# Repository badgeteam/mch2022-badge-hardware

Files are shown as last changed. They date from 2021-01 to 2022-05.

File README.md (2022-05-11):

# MCH2022 badge hardware

The hardware design files for the MCH2022 event badge.

## Documentation

Detailed information can be found on our website at https://badge.team/docs/badges/mch2022/.

Need the schematic? [It's in this repository as a PDF file](schematic.pdf).

## Firmware

There are multiple processors on this board, the firmware flashed on to the board in the factory can be found in the following repositories:

 - https://github.com/badgeteam/mch2022-firmware-esp32
 - https://github.com/badgeteam/mch2022-firmware-rp2040

## License

This hardware design may be used under the terms of the [CERN-OHL-P](LICENSE) license.

## Authors

The artwork featured in this hardware design has been designed by Nikolett S. from [tilde.industries](https://tilde.industries).

The electronics have been designed by Renze Nicolai from [Nicolai Electronics](https://nicolaielectronics.nl).

A special thanks to all who contributed by helping with the routing and by debugging the hardware design:

 - Anne Jan Brouwer
 - Kliment Yanev
 - Kuristian
 - Martin Ling
 - Paul Honig
 - Sylvain Munaut
 - Tom Clement
 - Fuchsia (f0x)
 - Sander de Haan

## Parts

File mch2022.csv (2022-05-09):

Source: | /home/renze/Documents/Badge.team/mch2022-badge-hardware/mch2022.kicad_sch
Date: | Mon 09 May 2022 05:42:22 PM CEST
Tool: | Eeschema (6.0.5)
Generator: | /usr/share/kicad/plugins/bom_csv_grouped_by_value.py
Component Count: | 235
Individual Components:
Item | Qty | Reference(s) | Value | LibPart | Footprint | Datasheet | AVAILABILITY | Buy early | Category | DESCRIPTION | DK_Datasheet_Link | DK_Detail_Page | Description | Digi-Key_PN | Family | Field4 | LCSC | MANUFACTURER | MAXIMUM_PACKAGE_HEIGHT | MF | MP | MPN | Manufacturer | Minimal voltage rating | Mouser | PACKAGE | PARTREV | PRICE | Price | STANDARD | Sponsored | Status | Voltage rating
 |  | C1 | 1u | mch2021-rescue:C-Device | Capacitor_SMD:C_0402_1005Metric | https://datasheet.lcsc.com/lcsc/1810191216_Samsung-Electro-Mechanics-CL05A105KQ5NNNC_C107372.pdf |  | Y | Capacitors |  |  |  | Generic part |  |  |  | C107372 |  |  |  |  | CL05A105KQ5NNNC | Samsung Electro-Mechanics | 6 |  |  |  |  |  |  | N |  | 6.3
 |  | C3 | 100n | mch2021-rescue:C-Device | Capacitor_SMD:C_0402_1005Metric | https://datasheet.lcsc.com/lcsc/1810191222_Samsung-Electro-Mechanics-CL05B104KB54PNC_C307331.pdf |  | Y | Capacitors |  |  |  | Generic part |  |  |  | C307331 |  |  |  |  | CL05B104KB54PNC | Samsung Electro-Mechanics | 10 |  |  |  |  |  |  | N |  | 50
 |  | C4 | 100n | Device:C_Small | Capacitor_SMD:C_0402_1005Metric | https://datasheet.lcsc.com/lcsc/1810191222_Samsung-Electro-Mechanics-CL05B104KB54PNC_C307331.pdf |  | Y | Capacitors |  |  |  | Generic part |  |  |  | C307331 |  |  |  |  | CL05B104KB54PNC | Samsung Electro-Mechanics | 10 |  |  |  |  |  |  | N |  | 50
 |  | C5 | 47u | Device:C_Small | Capacitor_SMD:C_0805_2012Metric | https://datasheet.lcsc.com/lcsc/1811091612_Samsung-Electro-Mechanics-CL21A476MQYNNNE_C16780.pdf |  | Y | Capacitors |  |  |  | Generic part |  |  |  | C16780 |  |  |  |  | CL21A476MQYNNNE | Samsung Electro-Mechanics | 6 |  |  |  |  |  |  | N |  | 6.3
 |  | C6 | 47u | Device:C_Small | Capacitor_SMD:C_0805_2012Metric | https://datasheet.lcsc.com/lcsc/1811091612_Samsung-Electro-Mechanics-CL21A476MQYNNNE_C16780.pdf |  | Y | Capacitors |  |  |  | Generic part |  |  |  | C16780 |  |  |  |  | CL21A476MQYNNNE | Samsung Electro-Mechanics | 6 |  |  |  |  |  |  | N |  | 6.3
 |  | C7 | 100n | mch2021-rescue:C-Device | Capacitor_SMD:C_0402_1005Metric | https://datasheet.lcsc.com/lcsc/1810191222_Samsung-Electro-Mechanics-CL05B104KB54PNC_C307331.pdf |  | Y | Capacitors |  |  |  | Generic part |  |  |  | C307331 |  |  |  |  | CL05B104KB54PNC | Samsung Electro-Mechanics | 10 | - |  |  |  |  |  | N |  | 50
 |  | C8 | 1u | mch2021-rescue:C-Device | Capacitor_SMD:C_0402_1005Metric | https://datasheet.lcsc.com/lcsc/1810191216_Samsung-Electro-Mechanics-CL05A105KQ5NNNC_C107372.pdf |  | Y | Capacitors |  |  |  | Generic part |  |  |  | C107372 |  |  |  |  | CL05A105KQ5NNNC | Samsung Electro-Mechanics | 6 | - |  |  |  |  |  | N |  | 6.3
 |  | C9 | 22p | mch2021-rescue:C-Device | Capacitor_SMD:C_0402_1005Metric | https://datasheet.lcsc.com/lcsc/1912111437_CCTC-TCC0402C0G220J500AT_C466226.pdf |  | Y | Capacitors |  |  |  | Generic part |  |  |  | C466226 | YAGEO |  |  |  | TCC0402C0G220J500AT | CCTC | 10 |  |  |  |  |  |  | N |  | 50
 |  | C10 | 22p | mch2021-rescue:C-Device | Capacitor_SMD:C_0402_1005Metric | https://datasheet.lcsc.com/lcsc/1912111437_CCTC-TCC0402C0G220J500AT_C466226.pdf |  | Y | Capacitors |  |  |  | Generic part |  |  |  | C466226 | YAGEO |  |  |  | TCC0402C0G220J500AT | CCTC | 10 |  |  |  |  |  |  | N |  | 50
 |  | C11 | 100n | mch2021-rescue:C-Device | Capacitor_SMD:C_0402_1005Metric | https://datasheet.lcsc.com/lcsc/1810191222_Samsung-Electro-Mechanics-CL05B104KB54PNC_C307331.pdf |  | Y | Capacitors |  |  |  | Generic part |  |  |  | C307331 |  |  |  |  | CL05B104KB54PNC | Samsung Electro-Mechanics | 10 | - |  |  |  |  |  | N |  | 50
 |  | C12 | 100n | mch2021-rescue:C_Small-Device | Capacitor_SMD:C_0402_1005Metric | https://datasheet.lcsc.com/lcsc/1810191222_Samsung-Electro-Mechanics-CL05B104KB54PNC_C307331.pdf |  | Y | Capacitors |  |  |  | Generic part |  |  |  | C307331 |  |  |  |  | CL05B104KB54PNC | Samsung Electro-Mechanics | 10 | - |  |  |  |  |  | N |  | 50
 |  | C13 | 100n | mch2021-rescue:C-Device | Capacitor_SMD:C_0402_1005Metric | https://datasheet.lcsc.com/lcsc/1810191222_Samsung-Electro-Mechanics-CL05B104KB54PNC_C307331.pdf |  | Y | Capacitors |  |  |  | Generic part |  |  |  | C307331 |  |  |  |  | CL05B104KB54PNC | Samsung Electro-Mechanics | 10 | - |  |  |  |  |  | N |  | 50
 |  | C14 | 100n | Device:C_Small | Capacitor_SMD:C_0402_1005Metric | https://datasheet.lcsc.com/lcsc/1810191222_Samsung-Electro-Mechanics-CL05B104KB54PNC_C307331.pdf |  | Y | Capacitors |  |  |  | Generic part |  |  |  | C307331 |  |  |  |  | CL05B104KB54PNC | Samsung Electro-Mechanics | 10 |  |  |  |  |  |  | N |  | 50
 |  | C15 | 100n | mch2021-rescue:C_Small-Device | Capacitor_SMD:C_0402_1005Metric | https://datasheet.lcsc.com/lcsc/1810191222_Samsung-Electro-Mechanics-CL05B104KB54PNC_C307331.pdf |  | Y | Capacitors |  |  |  | Generic part |  |  |  | C307331 |  |  |  |  | CL05B104KB54PNC | Samsung Electro-Mechanics | 10 | - |  |  |  |  |  | N |  | 50
 |  | C16 | 100n | mch2021-rescue:C_Small-Device | Capacitor_SMD:C_0402_1005Metric | https://datasheet.lcsc.com/lcsc/1810191222_Samsung-Electro-Mechanics-CL05B104KB54PNC_C307331.pdf |  | Y | Capacitors |  |  |  | Generic part |  |  |  | C307331 |  |  |  |  | CL05B104KB54PNC | Samsung Electro-Mechanics | 10 | - |  |  |  |  |  | N |  | 50
 |  | C17 | 10u | mch2021-rescue:C_Small-Device | Capacitor_SMD:C_0402_1005Metric | https://datasheet.lcsc.com/lcsc/1810191215_Samsung-Electro-Mechanics-CL05A106MQ5NUNC_C15525.pdf |  | Y | Capacitors |  |  |  | Generic part |  |  |  | C15525 |  |  |  |  | CL05A106MQ5NUNC | Samsung Electro-Mechanics | 6 |  |  |  |  |  |  | N |  | 6.3
 |  | C18 | 100n | mch2021-rescue:C_Small-Device | Capacitor_SMD:C_0402_1005Metric | https://datasheet.lcsc.com/lcsc/1810191222_Samsung-Electro-Mechanics-CL05B104KB54PNC_C307331.pdf |  | Y | Capacitors |  |  |  | Generic part |  |  |  | C307331 |  |  |  |  | CL05B104KB54PNC | Samsung Electro-Mechanics | 10 | - |  |  |  |  |  | N |  | 50
 |  | C19 | 100n | mch2021-rescue:C_Small-Device | Capacitor_SMD:C_0402_1005Metric | https://datasheet.lcsc.com/lcsc/1810191222_Samsung-Electro-Mechanics-CL05B104KB54PNC_C307331.pdf |  | Y | Capacitors |  |  |  | Generic part |  |  |  | C307331 |  |  |  |  | CL05B104KB54PNC | Samsung Electro-Mechanics | 10 | - |  |  |  |  |  | N |  | 50
 |  | C20 | 100n | mch2021-rescue:C_Small-Device | Capacitor_SMD:C_0402_1005Metric | https://datasheet.lcsc.com/lcsc/1810191222_Samsung-Electro-Mechanics-CL05B104KB54PNC_C307331.pdf |  | Y | Capacitors |  |  |  | Generic part |  |  |  | C307331 |  |  |  |  | CL05B104KB54PNC | Samsung Electro-Mechanics | 10 | - |  |  |  |  |  | N |  | 50
 |  | C21 | 100n | mch2021-rescue:C_Small-Device | Capacitor_SMD:C_0402_1005Metric | https://datasheet.lcsc.com/lcsc/1810191222_Samsung-Electro-Mechanics-CL05B104KB54PNC_C307331.pdf |  | Y | Capacitors |  |  |  | Generic part |  |  |  | C307331 |  |  |  |  | CL05B104KB54PNC | Samsung Electro-Mechanics | 10 | - |  |  |  |  |  | N |  | 50
 |  | C22 | 100n | mch2021-rescue:C_Small-Device | Capacitor_SMD:C_0402_1005Metric | https://datasheet.lcsc.com/lcsc/1810191222_Samsung-Electro-Mechanics-CL05B104KB54PNC_C307331.pdf |  | Y | Capacitors |  |  |  | Generic part |  |  |  | C307331 |  |  |  |  | CL05B104KB54PNC | Samsung Electro-Mechanics | 10 | - |  |  |  |  |  | N |  | 50
 |  | C23 | 100n | mch2021-rescue:C-Device | Capacitor_SMD:C_0402_1005Metric | https://datasheet.lcsc.com/lcsc/1810191222_Samsung-Electro-Mechanics-CL05B104KB54PNC_C307331.pdf |  | Y | Capacitors |  |  |  | Generic part |  |  |  | C307331 |  |  |  |  | CL05B104KB54PNC | Samsung Electro-Mechanics | 10 | - |  |  |  |  |  | N |  | 50
 |  | C24 | 100n | mch2021-rescue:C-Device | Capacitor_SMD:C_0402_1005Metric | https://datasheet.lcsc.com/lcsc/1810191222_Samsung-Electro-Mechanics-CL05B104KB54PNC_C307331.pdf |  | Y | Capacitors |  |  |  | Generic part |  |  |  | C307331 |  |  |  |  | CL05B104KB54PNC | Samsung Electro-Mechanics | 10 | - |  |  |  |  |  | N |  | 50
 |  | C25 | 10u | mch2021-rescue:C-Device | Capacitor_SMD:C_0402_1005Metric | https://datasheet.lcsc.com/lcsc/1810191215_Samsung-Electro-Mechanics-CL05A106MQ5NUNC_C15525.pdf |  | Y | Capacitors |  |  |  | Generic part |  |  |  | C15525 |  |  |  |  | CL05A106MQ5NUNC | Samsung Electro-Mechanics | 6 |  |  |  |  |  |  | N |  | 6.3
 |  | C26 | 100n | mch2021-rescue:C-Device | Capacitor_SMD:C_0402_1005Metric | https://datasheet.lcsc.com/lcsc/1810191222_Samsung-Electro-Mechanics-CL05B104KB54PNC_C307331.pdf |  | Y | Capacitors |  |  |  | Generic part |  |  |  | C307331 |  |  |  |  | CL05B104KB54PNC | Samsung Electro-Mechanics | 10 | - |  |  |  |  |  | N |  | 50
 |  | C27 | 100n | mch2021-rescue:C-Device | Capacitor_SMD:C_0402_1005Metric | https://datasheet.lcsc.com/lcsc/1810191222_Samsung-Electro-Mechanics-CL05B104KB54PNC_C307331.pdf |  | Y | Capacitors |  |  |  | Generic part |  |  |  | C307331 |  |  |  |  | CL05B104KB54PNC | Samsung Electro-Mechanics | 10 | - |  |  |  |  |  | N |  | 50
 |  | C28 | 22p | mch2021-rescue:C-Device | Capacitor_SMD:C_0402_1005Metric | https://datasheet.lcsc.com/lcsc/1912111437_CCTC-TCC0402C0G220J500AT_C466226.pdf |  | Y | Capacitors |  |  |  | Generic part |  |  |  | C466226 | YAGEO |  |  |  | TCC0402C0G220J500AT | CCTC | 10 |  |  |  |  |  |  | N |  | 50
 |  | C29 | 22p | mch2021-rescue:C-Device | Capacitor_SMD:C_0402_1005Metric | https://datasheet.lcsc.com/lcsc/1912111437_CCTC-TCC0402C0G220J500AT_C466226.pdf |  | Y | Capacitors |  |  |  | Generic part |  |  |  | C466226 | YAGEO |  |  |  | TCC0402C0G220J500AT | CCTC | 10 |  |  |  |  |  |  | N |  | 50
 |  | C30 | 100n | mch2021-rescue:C-Device | Capacitor_SMD:C_0402_1005Metric | https://datasheet.lcsc.com/lcsc/1810191222_Samsung-Electro-Mechanics-CL05B104KB54PNC_C307331.pdf |  | Y | Capacitors |  |  |  | Generic part |  |  |  | C307331 |  |  |  |  | CL05B104KB54PNC | Samsung Electro-Mechanics | 10 | - |  |  |  |  |  | N |  | 50
 |  | C31 | 1u | mch2021-rescue:C-Device | Capacitor_SMD:C_0402_1005Metric | https://datasheet.lcsc.com/lcsc/1810191216_Samsung-Electro-Mechanics-CL05A105KQ5NNNC_C107372.pdf |  | Y | Capacitors |  |  |  | Generic part |  |  |  | C107372 |  |  |  |  | CL05A105KQ5NNNC | Samsung Electro-Mechanics | 6 |  |  |  |  |  |  | N |  | 6.3
 |  | C32 | 1u | mch2021-rescue:C-Device | Capacitor_SMD:C_0402_1005Metric | https://datasheet.lcsc.com/lcsc/1810191216_Samsung-Electro-Mechanics-CL05A105KQ5NNNC_C107372.pdf |  | Y | Capacitors |  |  |  | Generic part |  |  |  | C107372 |  |  |  |  | CL05A105KQ5NNNC | Samsung Electro-Mechanics | 6 |  |  |  |  |  |  | N |  | 6.3
 |  | C33 | 100n | Device:C_Small | Capacitor_SMD:C_0402_1005Metric | https://datasheet.lcsc.com/lcsc/1810191222_Samsung-Electro-Mechanics-CL05B104KB54PNC_C307331.pdf |  | Y | Capacitors |  |  |  | Generic part |  |  |  | C307331 |  |  |  |  | CL05B104KB54PNC | Samsung Electro-Mechanics | 10 |  |  |  |  |  |  | N |  | 50
 |  | C34 | 10u | mch2021-rescue:C-Device | Capacitor_SMD:C_0402_1005Metric | https://datasheet.lcsc.com/lcsc/1810191215_Samsung-Electro-Mechanics-CL05A106MQ5NUNC_C15525.pdf |  | Y | Capacitors |  |  |  | Generic part |  |  |  | C15525 |  |  |  |  | CL05A106MQ5NUNC | Samsung Electro-Mechanics | 6 |  |  |  |  |  |  | N |  | 6.3
 |  | C35 | 100n | mch2021-rescue:C-Device | Capacitor_SMD:C_0402_1005Metric | https://datasheet.lcsc.com/lcsc/1810191222_Samsung-Electro-Mechanics-CL05B104KB54PNC_C307331.pdf |  | Y | Capacitors |  |  |  | Generic part |  |  |  | C307331 |  |  |  |  | CL05B104KB54PNC | Samsung Electro-Mechanics | 10 |  |  |  |  |  |  | N |  | 50
 |  | C36 | 100n | mch2021-rescue:C-Device | Capacitor_SMD:C_0402_1005Metric | https://datasheet.lcsc.com/lcsc/1810191222_Samsung-Electro-Mechanics-CL05B104KB54PNC_C307331.pdf |  | Y | Capacitors |  |  |  | Generic part |  |  |  | C307331 |  |  |  |  | CL05B104KB54PNC | Samsung Electro-Mechanics | 10 |  |  |  |  |  |  | N |  | 50
 |  | C37 | 100n | mch2021-rescue:C-Device | Capacitor_SMD:C_0402_1005Metric | https://datasheet.lcsc.com/lcsc/1810191222_Samsung-Electro-Mechanics-CL05B104KB54PNC_C307331.pdf |  | Y | Capacitors |  |  |  | Generic part |  |  |  | C307331 |  |  |  |  | CL05B104KB54PNC | Samsung Electro-Mechanics | 10 | - |  |  |  |  |  | N |  | 50
 |  | C38 | 22u | mch2021-rescue:C-Device | Capacitor_SMD:C_0805_2012Metric | https://datasheet.lcsc.com/lcsc/2006102223_Samsung-Electro-Mechanics-CL21A226MAYNNNE_C602037.pdf |  | Y | Capacitors |  |  |  | Generic part |  |  |  | C602037 |  |  |  |  | CL21A226MAYNNNE | Samsung Electro-Mechanics | 10 |  |  |  |  |  |  | N |  | 25
 |  | C39 | 22u | mch2021-rescue:C-Device | Capacitor_SMD:C_0805_2012Metric | https://datasheet.lcsc.com/lcsc/2006102223_Samsung-Electro-Mechanics-CL21A226MAYNNNE_C602037.pdf |  | Y | Capacitors |  |  |  | Generic part |  |  |  | C602037 |  |  |  |  | CL21A226MAYNNNE | Samsung Electro-Mechanics | 10 |  |  |  |  |  |  | N |  | 25
 |  | C40 | 22p | mch2021-rescue:C-Device | Capacitor_SMD:C_0402_1005Metric | https://datasheet.lcsc.com/lcsc/1912111437_CCTC-TCC0402C0G220J500AT_C466226.pdf |  | Y | Capacitors |  |  |  | Generic part |  |  |  | C466226 | YAGEO |  |  |  | TCC0402C0G220J500AT | CCTC | 10 |  |  |  |  |  |  | N |  | 50
 |  | C41 | 22p | mch2021-rescue:C-Device | Capacitor_SMD:C_0402_1005Metric | https://datasheet.lcsc.com/lcsc/1912111437_CCTC-TCC0402C0G220J500AT_C466226.pdf |  | Y | Capacitors |  |  |  | Generic part |  |  |  | C466226 | YAGEO |  |  |  | TCC0402C0G220J500AT | CCTC | 10 |  |  |  |  |  |  | N |  | 50
 |  | C42 | 10u | mch2021-rescue:C-Device | Capacitor_SMD:C_0402_1005Metric | https://datasheet.lcsc.com/lcsc/1810191215_Samsung-Electro-Mechanics-CL05A106MQ5NUNC_C15525.pdf |  | Y | Capacitors |  |  |  | Generic part |  |  |  | C15525 |  |  |  |  | CL05A106MQ5NUNC | Samsung Electro-Mechanics | 6 |  |  |  |  |  |  | N |  | 6.3
 |  | C43 | 22u | mch2021-rescue:C-Device | Capacitor_SMD:C_0805_2012Metric | https://datasheet.lcsc.com/lcsc/2006102223_Samsung-Electro-Mechanics-CL21A226MAYNNNE_C602037.pdf |  | Y | Capacitors |  |  |  | Generic part |  |  |  | C602037 |  |  |  |  | CL21A226MAYNNNE | Samsung Electro-Mechanics | 10 |  |  |  |  |  |  | N |  | 25
 |  | C44 | 22u | mch2021-rescue:C-Device | Capacitor_SMD:C_0805_2012Metric | https://datasheet.lcsc.com/lcsc/2006102223_Samsung-Electro-Mechanics-CL21A226MAYNNNE_C602037.pdf |  | Y | Capacitors |  |  |  | Generic part |  |  |  | C602037 |  |  |  |  | CL21A226MAYNNNE | Samsung Electro-Mechanics | 10 |  |  |  |  |  |  | N |  | 25
 |  | C45 | 22u | mch2021-rescue:C-Device | Capacitor_SMD:C_0805_2012Metric | https://datasheet.lcsc.com/lcsc/2006102223_Samsung-Electro-Mechanics-CL21A226MAYNNNE_C602037.pdf |  | Y | Capacitors |  |  |  | Generic part |  |  |  | C602037 |  |  |  |  | CL21A226MAYNNNE | Samsung Electro-Mechanics | 10 |  |  |  |  |  |  | N |  | 25
 |  | C46 | 22u | mch2021-rescue:C-Device | Capacitor_SMD:C_0805_2012Metric | https://datasheet.lcsc.com/lcsc/2006102223_Samsung-Electro-Mechanics-CL21A226MAYNNNE_C602037.pdf |  | Y | Capacitors |  |  |  | Generic part |  |  |  | C602037 |  |  |  |  | CL21A226MAYNNNE | Samsung Electro-Mechanics | 10 |  |  |  |  |  |  | N |  | 25
 |  | C47 | 39n | Device:C_Small | Capacitor_SMD:C_0402_1005Metric | https://datasheet.lcsc.com/lcsc/2010152035_CCTC-TCC0402X7R393K500AT_C880624.pdf |  | Y | Capacitors |  |  |  | Generic part |  |  |  | C880624 |  |  |  |  | TCC0402X7R393K500AT | CCTC | 10 |  |  |  |  |  |  | N |  | 50
 |  | C48 | 100n | mch2021-rescue:C-Device | Capacitor_SMD:C_0402_1005Metric | https://datasheet.lcsc.com/lcsc/1810191222_Samsung-Electro-Mechanics-CL05B104KB54PNC_C307331.pdf |  | Y | Capacitors |  |  |  | Generic part |  |  |  | C307331 |  |  |  |  | CL05B104KB54PNC | Samsung Electro-Mechanics | 10 | - |  |  |  |  |  | N |  | 50
 |  | C49 | 22u | mch2021-rescue:C-Device | Capacitor_SMD:C_0805_2012Metric | https://datasheet.lcsc.com/lcsc/2006102223_Samsung-Electro-Mechanics-CL21A226MAYNNNE_C602037.pdf |  | Y | Capacitors |  |  |  | Generic part |  |  |  | C602037 |  |  |  |  | CL21A226MAYNNNE | Samsung Electro-Mechanics | 10 |  |  |  |  |  |  | N |  | 25
 |  | C50 | 100n | mch2021-rescue:C-Device | Capacitor_SMD:C_0402_1005Metric | https://datasheet.lcsc.com/lcsc/1810191222_Samsung-Electro-Mechanics-CL05B104KB54PNC_C307331.pdf |  | Y | Capacitors |  |  |  | Generic part |  |  |  | C307331 |  |  |  |  | CL05B104KB54PNC | Samsung Electro-Mechanics | 10 | - |  |  |  |  |  | N |  | 50
 |  | C51 | 39n | Device:C_Small | Capacitor_SMD:C_0402_1005Metric | https://datasheet.lcsc.com/lcsc/2010152035_CCTC-TCC0402X7R393K500AT_C880624.pdf |  | Y | Capacitors |  |  |  | Generic part |  |  |  | C880624 |  |  |  |  | TCC0402X7R393K500AT | CCTC | 10 |  |  |  |  |  |  | N |  | 50
 |  | C52 | 47u | Device:C_Small | Capacitor_SMD:C_0805_2012Metric | https://datasheet.lcsc.com/lcsc/1811091612_Samsung-Electro-Mechanics-CL21A476MQYNNNE_C16780.pdf |  | Y | Capacitors |  |  |  | Generic part |  |  |  | C16780 |  |  |  |  | CL21A476MQYNNNE | Samsung Electro-Mechanics | 6 |  |  |  |  |  |  | N |  | 6.3
 |  | C53 | 47u | Device:C_Small | Capacitor_SMD:C_0805_2012Metric | https://datasheet.lcsc.com/lcsc/1811091612_Samsung-Electro-Mechanics-CL21A476MQYNNNE_C16780.pdf |  | Y | Capacitors |  |  |  | Generic part |  |  |  | C16780 |  |  |  |  | CL21A476MQYNNNE | Samsung Electro-Mechanics | 6 |  |  |  |  |  |  | N |  | 6.3
 |  | C54 | 47u | Device:C_Small | Capacitor_SMD:C_0805_2012Metric | https://datasheet.lcsc.com/lcsc/1811091612_Samsung-Electro-Mechanics-CL21A476MQYNNNE_C16780.pdf |  | Y | Capacitors |  |  |  | Generic part |  |  |  | C16780 |  |  |  |  | CL21A476MQYNNNE | Samsung Electro-Mechanics | 6 |  |  |  |  |  |  | N |  | 6.3
 |  | C55 | 47u | Device:C_Small | Capacitor_SMD:C_0805_2012Metric | https://datasheet.lcsc.com/lcsc/1811091612_Samsung-Electro-Mechanics-CL21A476MQYNNNE_C16780.pdf |  | Y | Capacitors |  |  |  | Generic part |  |  |  | C16780 |  |  |  |  | CL21A476MQYNNNE | Samsung Electro-Mechanics | 6 |  |  |  |  |  |  | N |  | 6.3
 |  | C56 | 100n | Device:C_Small | Capacitor_SMD:C_0402_1005Metric | https://datasheet.lcsc.com/lcsc/1810191222_Samsung-Electro-Mechanics-CL05B104KB54PNC_C307331.pdf |  | Y | Capacitors |  |  |  | Generic part |  |  |  | C307331 |  |  |  |  | CL05B104KB54PNC | Samsung Electro-Mechanics | 10 |  |  |  |  |  |  | N |  | 50
 |  | C57 | 47u | Device:C_Small | Capacitor_SMD:C_0805_2012Metric | https://datasheet.lcsc.com/lcsc/1811091612_Samsung-Electro-Mechanics-CL21A476MQYNNNE_C16780.pdf |  | Y | Capacitors |  |  |  | Generic part |  |  |  | C16780 |  |  |  |  | CL21A476MQYNNNE | Samsung Electro-Mechanics | 6 |  |  |  |  |  |  | N |  | 6.3
 |  | C58 | 100n | mch2021-rescue:C-Device | Capacitor_SMD:C_0402_1005Metric | https://datasheet.lcsc.com/lcsc/1810191222_Samsung-Electro-Mechanics-CL05B104KB54PNC_C307331.pdf |  | Y | Capacitors |  |  |  | Generic part |  |  |  | C307331 |  |  |  |  | CL05B104KB54PNC | Samsung Electro-Mechanics | 10 | - |  |  |  |  |  | N |  | 50
 |  | C59 | 100n | mch2021-rescue:C-Device | Capacitor_SMD:C_0402_1005Metric | https://datasheet.lcsc.com/lcsc/1810191222_Samsung-Electro-Mechanics-CL05B104KB54PNC_C307331.pdf |  | Y | Capacitors |  |  |  | Generic part |  |  |  | C307331 |  |  |  |  | CL05B104KB54PNC | Samsung Electro-Mechanics | 10 | - |  |  |  |  |  | N |  | 50
 |  | C60 | 100n | mch2021-rescue:C-Device | Capacitor_SMD:C_0402_1005Metric | https://datasheet.lcsc.com/lcsc/1810191222_Samsung-Electro-Mechanics-CL05B104KB54PNC_C307331.pdf |  | Y | Capacitors |  |  |  | Generic part |  |  |  | C307331 |  |  |  |  | CL05B104KB54PNC | Samsung Electro-Mechanics | 10 | - |  |  |  |  |  | N |  | 50
 |  | C61 | 100n | mch2021-rescue:C-Device | Capacitor_SMD:C_0402_1005Metric | https://datasheet.lcsc.com/lcsc/1810191222_Samsung-Electro-Mechanics-CL05B104KB54PNC_C307331.pdf |  | Y | Capacitors |  |  |  | Generic part |  |  |  | C307331 |  |  |  |  | CL05B104KB54PNC | Samsung Electro-Mechanics | 10 | - |  |  |  |  |  | N |  | 50
 |  | C62 | 1u | mch2021-rescue:C-Device | Capacitor_SMD:C_0402_1005Metric | https://datasheet.lcsc.com/lcsc/1810191216_Samsung-Electro-Mechanics-CL05A105KQ5NNNC_C107372.pdf |  | Y | Capacitors |  |  |  | Generic part |  |  |  | C107372 |  |  |  |  | CL05A105KQ5NNNC | Samsung Electro-Mechanics | 6 | - |  |  |  |  |  | N |  | 6.3
 |  | C63 | 100n | mch2021-rescue:C-Device | Capacitor_SMD:C_0402_1005Metric | https://datasheet.lcsc.com/lcsc/1810191222_Samsung-Electro-Mechanics-CL05B104KB54PNC_C307331.pdf |  | Y | Capacitors |  |  |  | Generic part |  |  |  | C307331 |  |  |  |  | CL05B104KB54PNC | Samsung Electro-Mechanics | 10 | - |  |  |  |  |  | N |  | 50
 |  | C64 | 47u | Device:C_Small | Capacitor_SMD:C_0805_2012Metric | https://datasheet.lcsc.com/lcsc/1811091612_Samsung-Electro-Mechanics-CL21A476MQYNNNE_C16780.pdf |  | Y | Capacitors |  |  |  | Generic part |  |  |  | C16780 |  |  |  |  | CL21A476MQYNNNE | Samsung Electro-Mechanics | 6 |  |  |  |  |  |  | N |  | 6.3
 |  | C65 | 47u | Device:C_Small | Capacitor_SMD:C_0805_2012Metric | https://datasheet.lcsc.com/lcsc/1811091612_Samsung-Electro-Mechanics-CL21A476MQYNNNE_C16780.pdf |  | Y | Capacitors |  |  |  | Generic part |  |  |  | C16780 |  |  |  |  | CL21A476MQYNNNE | Samsung Electro-Mechanics | 6 |  |  |  |  |  |  | N |  | 6.3
 |  | C66 | 47u | Device:C_Small | Capacitor_SMD:C_0805_2012Metric | https://datasheet.lcsc.com/lcsc/1811091612_Samsung-Electro-Mechanics-CL21A476MQYNNNE_C16780.pdf |  | Y | Capacitors |  |  |  | Generic part |  |  |  | C16780 |  |  |  |  | CL21A476MQYNNNE | Samsung Electro-Mechanics | 6 |  |  |  |  |  |  | N |  | 6.3
 |  | C67 | 47u | Device:C_Small | Capacitor_SMD:C_0805_2012Metric | https://datasheet.lcsc.com/lcsc/1811091612_Samsung-Electro-Mechanics-CL21A476MQYNNNE_C16780.pdf |  | Y | Capacitors |  |  |  | Generic part |  |  |  | C16780 |  |  |  |  | CL21A476MQYNNNE | Samsung Electro-Mechanics | 6 |  |  |  |  |  |  | N |  | 6.3
 |  | C68 | 100n | Device:C_Small | Capacitor_SMD:C_0402_1005Metric | https://datasheet.lcsc.com/lcsc/1810191222_Samsung-Electro-Mechanics-CL05B104KB54PNC_C307331.pdf |  | Y | Capacitors |  |  |  | Generic part |  |  |  | C307331 |  |  |  |  | CL05B104KB54PNC | Samsung Electro-Mechanics | 10 |  |  |  |  |  |  | N |  | 50
 |  | C69 | 100n | Device:C_Small | Capacitor_SMD:C_0402_1005Metric | https://datasheet.lcsc.com/lcsc/1810191222_Samsung-Electro-Mechanics-CL05B104KB54PNC_C307331.pdf |  | Y | Capacitors |  |  |  | Generic part |  |  |  | C307331 |  |  |  |  | CL05B104KB54PNC | Samsung Electro-Mechanics | 10 |  |  |  |  |  |  | N |  | 50
 |  | D2 | RGB-5050 | custom:RGB-5050-MCH | LED_SMD:LED_RGB_5050-6 | https://datasheet.lcsc.com/lcsc/1811131122_HONGLITRONIC-Hongli-Zhihui--HONGLITRONIC--HL-AF-5060H271BU46FU79GC-S1-THL_C219409.pdf |  | Y | LEDs |  |  |  | Generic part |  |  |  | C219409 |  |  |  |  | HL-AF-5060H271BU46FU79GC-S1-THL | Honglitronic |  | - |  |  |  |  |  | N
 |  | D3 | SK6805-EC15 | custom:SK6805-EC15 | custom:LED_SK6805_EC15_1.5x1.5mm | http://www.normandled.com/upload/202003/SK6805-EC15%20LED%20Datasheet.pdf |  | Y | LEDs |  |  |  | http://www.normandled.com/Product/view/id/842.html |  |  |  | - |  |  |  |  | SK6805-EC15 | Normandled |  | - |  |  |  |  |  | N
 |  | D4 | SK6805-EC15 | custom:SK6805-EC15 | custom:LED_SK6805_EC15_1.5x1.5mm | http://www.normandled.com/upload/202003/SK6805-EC15%20LED%20Datasheet.pdf |  | Y | LEDs |  |  |  | http://www.normandled.com/Product/view/id/842.html |  |  |  | - |  |  |  |  | SK6805-EC15 | Normandled |  | - |  |  |  |  |  | N
 |  | D5 | SK6805-EC15 | custom:SK6805-EC15 | custom:LED_SK6805_EC15_1.5x1.5mm | http://www.normandled.com/upload/202003/SK6805-EC15%20LED%20Datasheet.pdf |  | Y | LEDs |  |  |  | http://www.normandled.com/Product/view/id/842.html |  |  |  | - |  |  |  |  | SK6805-EC15 | Normandled |  | - |  |  |  |  |  | N
 |  | D6 | SK6805-EC15 | custom:SK6805-EC15 | custom:LED_SK6805_EC15_1.5x1.5mm | http://www.normandled.com/upload/202003/SK6805-EC15%20LED%20Datasheet.pdf |  | Y | LEDs |  |  |  | http://www.normandled.com/Product/view/id/842.html |  |  |  | - |  |  |  |  | SK6805-EC15 | Normandled |  | - |  |  |  |  |  | N
 |  | D7 | SK6805-EC15 | custom:SK6805-EC15 | custom:LED_SK6805_EC15_1.5x1.5mm | http://www.normandled.com/upload/202003/SK6805-EC15%20LED%20Datasheet.pdf |  | Y | LEDs |  |  |  | http://www.normandled.com/Product/view/id/842.html |  |  |  | - |  |  |  |  | SK6805-EC15 | Normandled |  | - |  |  |  |  |  | N
 |  | D8 | IR LED | Device:LED | LED_SMD:LED_0805_2012Metric | https://datasheet.lcsc.com/lcsc/2104131906_XINGLIGHT-XL-2012IRC-940_C965889.pdf |  | Y | LEDs |  |  |  | Infrared transmitter |  |  |  | C965889 |  |  |  |  | XL-2012IRC-940 | Xinglight
 |  | D9 | PSBD3D40V1H | mch2021-rescue:D_Schottky-Device | Diode_SMD:D_SOD-323 | https://datasheet.lcsc.com/lcsc/1810251323_Shanghai-Prisemi-Elec-PSBD3D40V1H_C110733.pdf |  | Y | Diodes |  |  |  | Generic part |  |  |  | C110733 |  |  |  |  | PSBD3D40V1H | Shanghai Prisemi Elec |  |  |  |  |  |  |  | N
 |  | F1 | 1A | mch2021-rescue:Polyfuse_Small-Device | Fuse:Fuse_0805_2012Metric | https://datasheet.lcsc.com/lcsc/1808280424_Brightking-Elec--TAIWAN-SMD0805B050TF_C269104.pdf |  | Y | Fuses |  |  |  | Generic part |  |  |  | C269104 |  |  |  |  | SMD0805B050TF | Brightking Elec |  |  |  |  |  |  |  | N
 |  | FID1 | Fiducial | Mechanical:Fiducial | Fiducial:Fiducial_1mm_Mask2mm | ~ |  |  | Fiducials
 |  | FID2 | Fiducial | Mechanical:Fiducial | Fiducial:Fiducial_1mm_Mask2mm | ~ |  |  | Fiducials
 |  | J1 | AudioJack3 | mch2021-rescue:AudioJack3-Connector | custom:Boom-audiojack-PJ-320B | https://datasheet.lcsc.com/lcsc/1811132022_BOOMELE-Boom-Precision-Elec-C18594_C18594.pdf |  | Y | Connectors |  |  |  |  |  |  |  | C18594 |  |  |  |  | C18594 | Boomele |  | - |  |  |  |  |  | N
 |  | J2 | USB_C_Receptacle_USB2.0 | mch2021-rescue:USB_C_Receptacle_USB2.0-Connector | Connector_USB:USB_C_Receptacle_HRO_TYPE-C-31-M-12 | https://datasheet.lcsc.com/lcsc/2108131730_Korean-Hroparts-Elec-TYPE-C-31-M-12_C165948.pdf |  | Y | Connectors |  |  |  |  |  |  |  | C165948 |  |  |  |  | TYPE-C-31-M-12 | Korean Hroparts Elec |  | - |  |  |  |  |  | N
 |  | J3 | I2C | mch2021-rescue:QWIIC_MCH | custom:1X04_1MM_RA_GND | https://datasheet.lcsc.com/lcsc/1811151533_JST-Sales-America-SM04B-SRSS-TB-LF-SN_C160404.pdf |  | Y | Connectors |  |  |  | Optional |  |  | CONN-13694 | C160404 |  |  |  |  | SM04B-SRSS-TB | JST |  |  |  |  |  |  |  | N
 |  | J4 | PMOD | mch2021-rescue:Conn_02x06_Odd_Even-Connector_Generic | Connector_PinSocket_2.54mm:PinSocket_2x06_P2.54mm_Horizontal | https://www.cjt.com/Upload/A2541.pdf |  | N | Connectors |  |  |  | DO NOT POPULATE |  |  |  | C239357 |  |  |  |  | A2541HWR-2x6P | CJT |  | - |  |  |  |  |  | N
 |  | J5 | Micro SD card | mch2021-rescue:Micro_SD_Card-Connector | custom:MicroSD-SOFNG-TF-002-H18 | http://katalog.we-online.de/em/datasheet/693072010801.pdf |  | Y | Connectors |  |  |  |  |  |  |  | C125814 | SOFNG |  |  |  | TF-002X-H18 | SOFNG |  | - |  |  |  |  |  | N
 |  | J6 | Battery | Connector_Generic_MountingPin:Conn_01x02_MountingPin | custom:JST_S2B-ZR-SM4A-TF(LF)(SN) | https://datasheet.lcsc.com/lcsc/1912111437_JST-Sales-America-S2B-ZR-SM4A-TF-LF-SN_C265329.pdf |  |  | Connectors |  |  |  |  |  |  |  | C265329 |  |  |  |  | S2B-ZR-SM4A-TF(LF)(SN) | JST
 |  | J7 | LCD | Connector_Generic_MountingPin:Conn_01x40_MountingPin | Connector_FFC-FPC:Hirose_FH12-40S-0.5SH_1x40-1MP_P0.50mm_Horizontal | https://datasheet.lcsc.com/lcsc/2109221430_XUNPU-FPC-05F-40PH20_C2856812.pdf |  | Y | Connectors |  |  |  |  |  |  |  | C2856812 | XUNPU |  |  |  | FPC-05F-40PH20 | XUNPU |  |  |  |  |  | 0.757 |  | N
 |  | L3 | 2.2u | mch2021-rescue:L-Device | custom:Inductor_MSC20FC | https://datasheet.lcsc.com/lcsc/1912111437_PSA-Prosperity-Dielectrics-MCS20FC-2R2MHC_C375944.pdf |  | Y | Inductors |  |  |  |  |  |  |  | C375944 |  |  |  |  | MCS20FC-2R2MHC | PSA |  | - |  |  |  |  |  | N
 |  | L4 | 2.2u | mch2021-rescue:L-Device | custom:Inductor_MSC20FC | https://datasheet.lcsc.com/lcsc/1912111437_PSA-Prosperity-Dielectrics-MCS20FC-2R2MHC_C375944.pdf |  | Y | Inductors |  |  |  |  |  |  |  | C375944 |  |  |  |  | MCS20FC-2R2MHC | PSA |  | - |  |  |  |  |  | N
 |  | LS1 | Speaker | Connector_Generic_MountingPin:Conn_01x02_MountingPin | Connector_Molex:Molex_PicoBlade_53261-0271_1x02-1MP_P1.25mm_Horizontal | ~ |  | N | Connectors |  |  |  |  |  |  |  |  |  |  |  |  |  |  |  |  |  |  |  |  |  | N
 |  | N1 | Logo | mch2021-rescue:Housing-Mechanical | custom:badgeteam |  |  | N | PCB footprint only |  |  |  |  |  |  |  |  |  |  |  |  |  |  |  |  |  |  |  |  |  | N
 |  | N2 | Artwork | mch2021-rescue:Housing-Mechanical | custom:prototype4 |  |  | N | PCB footprint only |  |  |  |  |  |  |  |  |  |  |  |  |  |  |  |  |  |  |  |  |  | N
 |  | N3 | May Contain Hardware | mch2021-rescue:Housing-Mechanical | custom:protoboard-squares-big |  |  | N | PCB footprint only |  |  |  |  |  |  |  |  |  |  |  |  |  |  |  |  |  |  |  |  |  | N
 |  | Q1 | AP2302B | mch2021-rescue:Q_NMOS_GSD-Device | Package_TO_SOT_SMD:SOT-23 | https://datasheet.lcsc.com/lcsc/1912111437_ALLPOWER-ShenZhen-Quan-Li-Semiconductor-AP2302B_C406812.pdf |  | Y | Transistors |  |  |  | Generic part (NMOS GSD) |  |  |  | C406812 | ALLPOWER |  |  |  | AP2302B | Allpower |  | - |  |  |  |  |  | N
 |  | Q2 | AP2302B | mch2021-rescue:Q_NMOS_GSD-Device | Package_TO_SOT_SMD:SOT-23 | https://datasheet.lcsc.com/lcsc/1912111437_ALLPOWER-ShenZhen-Quan-Li-Semiconductor-AP2302B_C406812.pdf |  | Y | Transistors |  |  |  | Generic part (NMOS GSD) |  |  |  | C406812 | ALLPOWER |  |  |  | AP2302B | Allpower |  | - |  |  |  |  |  | N
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

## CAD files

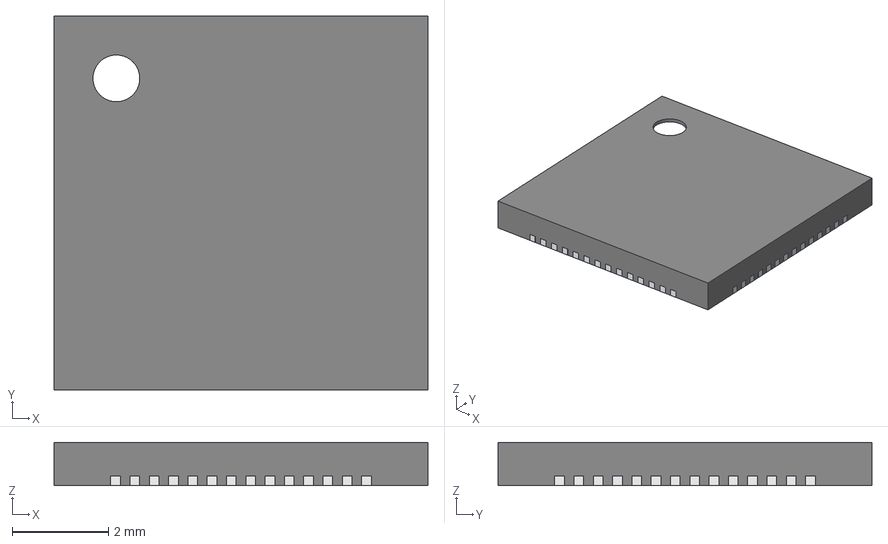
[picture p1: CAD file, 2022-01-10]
RP2040/RP2040.step
7.75 x 7.75 x 0.901 mm
Open_CASCADE_STEP_translator_6.8_5.1
Open_CASCADE_STEP_translator_6.8_5.2.1
Thermal_Shape
Open_CASCADE_STEP_translator_6.8_5.4.1 x 56

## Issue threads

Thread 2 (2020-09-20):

LCD SPI clock enable and Neopixel data enable inverted

renzenicolai, 2020-09-20:
The switch chips used for LCD clock and neopixel data have an active low enable input.

For the LCD the fix is easy as there is already an NPN transistor inverting the signal in the line.
For the Neopixel data line the workaround I use is to always enable the data line. This might be sufficient for the next version of the PCB too. The switch chip is then essentially used as a 3.3v to 5v level converter.

Closed 2020-10-11.

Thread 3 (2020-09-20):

Battery connector mirrored

renzenicolai, 2020-09-20:
The + and sensor pins have been swapped on proto 1. Added a bodge wire as workaround.

Closed 2020-11-22.

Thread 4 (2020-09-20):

FPGA SS pin needs pull-up

renzenicolai, 2020-09-20:
On cold boot the FPGA should be:

 - In RESET state (RESET line low)
 - Not active on the SPI bus (SS line high)

Proto 1 has the SS line pulled down. This must be changed to pull-up.

Note that the SS pin must be pulled low by the ESP32 before RESET is pulled high so that the ICE40 boots in SPI slave mode.

The fix has been tested (bodged by adding 10k pull-up and removing the ss pull-down resistor) to work.

Closed 2020-10-11.

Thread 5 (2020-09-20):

ESD protection on audio jack is wired up wrong

renzenicolai, 2020-09-20:
Current schematic prevents the voltage on the audio jack from going negative. Maybe we can move the ESD diodes to another place in the filter where we can have the signal be between 0 and 3.3v?

Closed 2020-11-22.

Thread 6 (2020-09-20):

Joystick needs to be moved 45 degrees

renzenicolai, 2020-09-20:
Joystick currently moves diagonally instead of horizontally and vertically as intended. Can be fixed by moving the footprint.

Closed 2020-10-11.

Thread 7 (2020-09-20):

Change power switch position in circuit to only turn off vbatt to system

renzenicolai, 2020-09-20:
On proto 1 moving the switch resets the microcontrollers. This can be prevented by moving the switch to only switch vbatt on/off but not interrupt the voltage coming out of the ideal diode.

Closed 2020-11-13.

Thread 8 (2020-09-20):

Use STM32 as RTC

renzenicolai, 2020-09-20:
- Connect STM32 to wakeup capable ESP32 pin
 - Connect STM32 vbatt pin to a separate always-on rail and add the RTC crystal so that the STM32 can be our real time clock

Closed 2020-11-22.

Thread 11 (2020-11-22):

Add I2S DAC circuit

renzenicolai, 2020-11-22:
Currently the schematic for the second prototype does not have a circuit for audio implemented.

renzenicolai, 2020-11-29:
Waiting for sponsorship query

renzenicolai, 2020-12-06:
Done

Closed 2020-12-06.

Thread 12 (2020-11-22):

SMD hooks and/or mounting holes for lanyard / case

renzenicolai, 2020-11-22:
Currently the MCH2021 prototype 2 PCB design does not have mounting holes and mounting hooks for the lanyard.

Bas thinks the SMD lanyard hooks used on the CZ19 badge might be usefull. Some other people asked for holes to attach a 3d printed case to.

sebastius, 2020-12-06:
If you're doing holes anyway: holes are cheaper 😊 But i really liked the SMD loops the Campzone 19 badge had. Mounting holes are essential for after-camp usage too (and for lasercut/3d printed cases)

renzenicolai, 2020-12-21:
Holes it is :smile:

Closed 2020-12-21.

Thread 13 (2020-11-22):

Connect STM32 to ESP32 RTC input pin

renzenicolai, 2020-11-22:
Connect the STM32 to the ESP32 in such a way that the STM32 can wake the ESP32 up from deep sleep mode.

Closed 2020-11-29.

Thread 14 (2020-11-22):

Resistor between ESP32 bootmode select pin (GPIO0) and STM32

renzenicolai, 2020-11-22:
GPIO0 is apparently set to output in some cases, we should add a resistor in series to prevent shorting out the GPIO0 pin and the output on the STM32 pulling this pin low for UART boot mode.

Closed 2020-11-29.

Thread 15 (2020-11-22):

Testpoint all the things

tjclement, 2020-11-22:
Would be good to add test points to at least all data buses, but also useful on e.g. main power rails

renzenicolai, 2020-12-06:
Done

Closed 2020-12-06.

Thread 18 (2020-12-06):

RGB LED pinout doesn't match either iCEBreaker or Upduino

xesxen, 2020-12-06:
We match with neither of these boards. To make things easier/more consistent for users I suggest we stick to either of these two (I would favour the iCEBreaker personally since that's an opensource design).

Upduino uses ([PDF](https://raw.githubusercontent.com/gtjennings1/UPDuino_v2_0/master/PCB/UPDuino_v2_0_C_121217.pdf)):
```
RGB0: Red
RGB1: Green
RGB2: Blue
```
iCEBreaker on the other hand uses ([KiCAD](https://github.com/icebreaker-fpga/icebreaker/tree/master/hardware/v1.0e)):
```
RGB0: Blue
RGB1: Green
RGB2: Red
```
while Proto2 currently uses
```
RGB0: Green
RGB1: Red
RGB2: Blue
```

sebastius, 2020-12-06:
That is something to fix in SW, right? Just a matter of pin definitions in some file? I haven't looked at it but pinwise, i'd go with what is easiest to route.

xesxen, 2020-12-06:
The pinconstraint is indeed just a plaintext file, but having it consistent with a popular board makes it easier for someone to just point to/use existing tutorials for RGB stuff :)

smunaut, 2020-12-06:
The pin constraint file isn't used for the RGB pins. Those have hardwired connections to the constant current driver Hard IP, you need to adapt the wiring in the verilog.

xesxen, 2020-12-06:
Are you sure? The iCEBreaker pcf clearly lists them as 'pins': https://github.com/osresearch/up5k/blob/master/icebreaker.pcf#L13-L16

smunaut, 2020-12-06:
Given I wrote the code in `nextpnr` to support the `SB_RGBA`  LED driver IP, yeah, I'm pretty sure.

They are in the PCF because you can still use those pins without using the constant current led drivers, as input or open drain (non current limited) outputs in which case the normal PCF applies. Also `nextpnr` will complain if they're not listed because ... reasons (pin locking is checked before we know what those pins are used for so at that point it doesn't know yet if they're used by the dedicated HW block)

sebastius, 2020-12-06:
> Given I wrote the code in `nextpnr` to support the `SB_RGBA` LED driver IP, yeah, I'm pretty sure.

Great to have you on board then! Thanks for helping out ☺️

xesxen, 2020-12-07:
Excuse me while I go eat my hat. Thanks for correcting me :)

renzenicolai, 2020-12-12:
Fixed, I chose to use the ICEbreaker pinout:

0: blue
1: green
2: red

Closed 2020-12-12.

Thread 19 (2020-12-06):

Potential overcurrent in the I2S data lines

xesxen, 2020-12-06:
When both the ESP32 and the FPGA is driving the I2S interface due to user error (or other reasons) there could be currents up to 35mA (3.3V@94Ohm). The iCE40 UP family specifies an max current of 8mA on 3V3 (Section `sysI/O Single-Ended DC Electrical Characteristics`), and some quick searching yield 12mA for the ESP32.

Maybe we should increase the resistor values from 47ohm to something a bit higher?

smunaut, 2020-12-06:
JFYI The UP5k drivers have roughly 50 ohm driver impedance.

https://github.com/YosysHQ/icestorm/wiki/UP5k-Driver-Characteristics

renzenicolai, 2020-12-12:
Changed the resistor values to 220 ohm, 7.5mA @ 3.3v

Closed 2020-12-12.

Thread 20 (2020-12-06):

RTC backup LDO

tachiniererin, 2020-12-06:
The AMS1117, U15 in the schematic won't be stable. It has a minimum load current requirement of 5mA typical, and worst case 10mA. In addition, it has a quiescent current of 5-11mA, which will drain the battery really fast.

In addition to that, the output capacitor is only 100nF, which is not enough to make it stable. In the datasheet it's specified with a 22µF tantalum (high ESR) capacitor, a ceramic capacitor has a magnitude less ESR in comparison.

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

sebastius, 2020-12-06:
Hmm yeah i agree on that the AMS1117 should be dropped for something better. Any suggestions?

tachiniererin, 2020-12-06:
Any requirements, e.g. does it have to be available from LCSC? I'll have a look in the morning.

sebastius, 2020-12-06:
We have a 'local agent' in China doing our purchasing so if LCSC doesnt have it, it might still be available. Our main goal is both cheap and efficient. Cheap in bulk (4000 badges are planned). LCSC would help/make things easier also for the prototype phase. It would mean that the LDO is readily available.

tachiniererin, 2020-12-07:
Depending on just how cost sensitive you are I would go either with TLV70433 (LCSC part number C94917) or as a cheaper alternative TLV74333 (LCSC part number C408972).

Both are stable with small MLCCs, so what they cost more you save in not needing an electrolytic (or worse, tantalum) capacitor.

sebastius, 2020-12-07:
it's all community money so the cheaper the better. I prefer not using tantalums, those are a fire hazard and contain a lot of slave labour.

tachiniererin, 2020-12-07:
A really low-cost alternative would be to supply the RTC through one or two silicon diodes to drop the battery voltage a bit. For example one or two 1N4148W in series, biased with a 200k resistor. Under no circumstances should Vbat then see more than 3.2V.
This then would have a static current consumption of 20µA including the RTC itself, which is even lower than the quiescent current of the cheaper LDO.

This solution would need to be tested though, because the characteristics of the diodes can vary a bit depending on the supplier. It might also be okay to reduce the bias current, if that's an optimization goal.

In total this would probably reduce the costs for this section to less than 1c per badge.

tachiniererin, 2020-12-07:
Adding a 3.3-V Zener would cancel out the temperature sensitivity of the previous solution:
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

This should be cheaper and better than any LDO for this particular job.

renzenicolai, 2020-12-12:
Added circuit with 3.3v zener instead of LDO

Closed 2020-12-12.

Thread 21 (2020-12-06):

Replace SD card load switch with a pMOS?

tachiniererin, 2020-12-06:
U4, SY6280AAC could be replaced by a logic level pMOS like AO3401 since the STM32 uses 3.3-V I/O. This would be cheaper and smaller.

renzenicolai, 2020-12-21:
Current solution works and the SY6280AAC is already in our BOM so: won't fix (for now).

Closed 2020-12-21.

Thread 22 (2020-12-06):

Bad choice of pin for clk input on FPGA

smunaut, 2020-12-06:
If you use pin 37 for clock input, you can't use the PLL of the FPGA.

There are some quirky rules on how this works, but the basic idea is that if the PLL is used then pin 37 can only be an output (you can't use it as input). And pin 35 can either be an output OR the input to the PLL (and input to the PLL only, you can't wire it as an input anywhere else).

My advice:
 * 35: CLK
 * 36: LCD_D6
 * 37: LCD_D7

That means LCD_D7 can only be an output but ... doesn't matter you have the `RD` signal wired to a constant on the LCD anyway so you can't read from it anyway.

renzenicolai, 2020-12-12:
Changed, thank you.

Closed 2020-12-12.

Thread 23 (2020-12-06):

Typo on FPGA symbol

smunaut, 2020-12-06:
`IOB_22b` is in fact `IOB_22a`

renzenicolai, 2020-12-18:
Heh, good find, this seems to be a bug in the official Kicad FPGA library

renzenicolai, 2020-12-18:
Created issue with upstream project https://gitlab.com/kicad/libraries/kicad-symbols/-/issues/3112

Closed 2020-12-18.

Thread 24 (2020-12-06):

FPGA: Clock "domain" shared between LCD and I2S IOs due to pin choice

smunaut, 2020-12-06:
So ... another quirk of that FPGA, some pairs of IO share the clock line driving them.

Here `IOT_48b` and `IOT_49a` are such a pair, which is a bit annoying that one is assigned to logic driving the LCD and another to logic driving the audio since you might want to have those in different clock domains.

I would try to have `I2S_DATA` and `I2S_LR` in an IO site pair like 38 / 42  and then have `I2S_CLK` on its own on pin 28.  (yeah I know it's a bit further but that's the only pin in that bank that's not in an IO pair).

renzenicolai, 2020-12-12:
Would you be willing to create a pinout sheet that maps the signal names on the schematic to the pins to which they should be connected? The changes you mention sound very usefull but it's a bit much to figure out while you seem to know the ins-and-outs of it :smile:

smunaut, 2020-12-13:
Here's what I ended up with:

```
25  IOT_36b  LCD_FMARK
23  IOT_37a  LCD_WR
27  IOT_38b  LCD_D1
26  IOT_39a  LCD_D0
28  IOT_41a  I2S_CLK
31  IOT_42b  LCD_D2
32  IOT_43a  LCD_D3
34  IOT_44b  LCD_D4
37  IOT_45a  LCD_D5
35  IOT_46b  CLK
36  IOT_48b  I2S_DATA
43  IOT_49a  I2S_LR
38  IOT_50b  LCD_D6
42  IOT_51a  LCD_D7
```

Couple of comments:
* `I2S_DATA` / `I2S_LR` can be swapped to ease routing
* I ended up using the `36` / `43` pair for I2S since `36` is a corner pin, it'll be easier to place a via to escape it out of all the LCD signals around it and `43` is also more on the outside.
* `28` Should also be near a "void" created with the power connections on neighbor pins so a via to escape it outside the LCD signal to join up with the other I2S shouldn't be an issue.

PS: Not done with the PR, just working through the other issues

renzenicolai, 2020-12-13:
I've merged the PR for now, together with a change that didn't conflict.

Will you let me know once you're done with your work? I don't mind if it takes a bit longer, thank you for your help!

smunaut, 2020-12-13:
Oh, I'm done. The comment above was because I made that comment like ... 3 hours before submitting the PR.

renzenicolai, 2020-12-13:
Thank you for your work, this will make the badge a much more usefull toy :-)

I've sent you an invitation to the badge.team github organisation, welcome! :smile:

smunaut, 2020-12-13:
Tx :)

Closed 2020-12-13.

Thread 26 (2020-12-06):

Schematic review

kliment, 2020-12-06:
Issues:

- [x] ESP32_EN needs 100n cap to GND to avoid glitching
- [x] R67/R68 should have higher value - at least 2k, to avoid large current source/sink if driven opposite ways by both signals
- [ ] PWR_LED should probably have a bulk capacitor
- [ ] Do the FPGA rails need power sequencing?

smunaut, 2020-12-06:
wrt to FPGA: Officially the 1v2 core of the FPGA must come before any of the other rails.
In practice, raising them at the same time never seemed to cause any issues.

kliment, 2020-12-06:
I don't see why we can't have the enable on the other vregs driven by the 1.2V regulator output. That gets us correct power sequencing for almost free.

zoe1337, 2020-12-06:
When we're adding caps to the ESP32 enable line, let's do the same for the STM32's nRESET lines!

smunaut, 2020-12-07:
wrt to R67/R68:

Using higher resistance reduces the maximum speed of the lines. Given how those leds are driven, you'd want your signal to have rising/falling edge well defined in time to preserve timing, so probably want a bandwidth ~ 10x the maximum rate, that would be 8 MHz here. With a 2k in series, that means the absolute maximum capacitance on the line would be 10pF. The U10 buffer has 4 pF input capacitance on its own, so any other parasitics need to stay low.

For the LED it might just stil work but for many other places that uses the same scheme, the frequencies involves are much higher and the bandwidth shouldn't be limited by a protection scheme.

The current is also not going to be _that_ high. Each driver has an output impedance, assuming they're are fairly strong it's be in the 25R range, plus the 2 47R, current is roughly 23 mA, the drivers should survive that without too much trouble. It can be bumped to 68R to bring it to 17.5 mA if more margin is wanted without much worries about bandwidth. But I guess 47R was chosen to reduce the BOM lines since it's used everywhere (including in places where the absolute values would matter)

renzenicolai, 2020-12-12:
Solved the first two issues.

3uF should be enough capacitance on the LED power line, I've even removed some caps.

FPGA is left in RESET state until it gets programmed, a long time after the power lines get stable. Power sequencing isn't going to be a problem in our case.

Closed 2020-12-12.

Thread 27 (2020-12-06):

FPGA: Pull up on CDONE

smunaut, 2020-12-06:
Technically the PCA9555PW has weak pull-ups but ...

The CDONE output is open-drain and it's important to note that if CDONE doesn't rise above Vih because it's not pulled up enough externally, the FPGA *will* *not* startup.

renzenicolai, 2020-12-07:
The I2C IO expander takes care of this, on prototype 1 the FPGA can be programmed and used as intended.

Closed 2020-12-07.

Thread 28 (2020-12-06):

USB input protection

tachiniererin, 2020-12-06:
The USBLC6-4 (D10) ESD protection specifies a worst case clamping voltage of 10V between Vbus and GND.
The SY8079 (U1 and U2) DC/DC converters have an absolute maximum input voltage of 7V. The power switch SY6280 (U14, among others) only of 6V.

When hot-plugging a long USB-cable, parasitic inductance and bulk capacitance can easily cause transients that not just briefly violate the abs. max rating, but also have enough energy to cause permanent damage.

Either higher voltage rated parts would be needed, or additional input protection; either a back-to-back pMOS pair (at least 30-V rated), or an integrated solution like an eFuse or an OR-ing controller (the latter could also handle the battery power switching).

Also a resettable fuse in series with USB Vbus is a good idea to protect the upstream USB port; this board is meant for tinkering, and accidents do happen.

renzenicolai, 2020-12-12:
Could you look at LCSC for a cheap suitable fuse?

tachiniererin, 2020-12-14:
I haven't found anything which is readily available and cost effective unfortunately. But i'll try to sketch a discrete solution in the coming days which takes a bit more space but should cost less than an ic.

zoe1337, 2020-12-20:
you can add a capacitor to the pass pFET's gate-source, slowing it down and preventing inrush

renzenicolai, 2020-12-21:
Added a fuse on the Vusb input, together with a ferrite bead in chip size. Should cover this stuff together with the 10u+100n capacitors.

Closed 2020-12-21.

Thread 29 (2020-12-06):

Flash voltage selection

tjclement, 2020-12-06:
I think the pull-up on ESP32's GPIO12 will cause the SPI flash to brown out, because the ESP32 will set it to 1.8v instead of the 3.3v that the WROVER B and E need; only the original WROVER works at 1.8v (and thus with GPIO12 pulled up)

https://www.espressif.com/sites/default/files/documentation/espressif_products_ordering_information_en.pdf
https://www.espressif.com/sites/default/files/documentation/esp32-wrover_datasheet_en.pdf ("strapping pins")
https://www.espressif.com/sites/default/files/documentation/esp32-wrover-b_datasheet_en.pdf
https://www.espressif.com/sites/default/files/documentation/esp32-wrover-e_esp32-wrover-ie_datasheet_en.pdf

sebastius, 2020-12-06:
Ah, same issue as we had on HackerHotel 2019? If i recall correctly you can burn a fuse to fix this, right?

martinling, 2020-12-11:
You can - the relevant fuses are `XPD_SDIO_REG`, `SDIO_TIEH` and `sdio_force`), in the "eFuse Controller" chapter in the ESP32 TRM: https://www.espressif.com/sites/default/files/documentation/esp32_technical_reference_manual_en.pdf

But that's an extra step you'd have to do for every single unit, so it would be a lot better to find a way to avoid needing a pullup on that line.

renzenicolai, 2020-12-12:
Swapped ext i2c with i2s clk/data pins and made IO12 have a pull-down.

I do suggest we burn these fuses and the write-protect fuses on any other unwanted option, that way we can be sure no-one accidentally bricks their badge / stop malicious software.

Closed 2020-12-12.

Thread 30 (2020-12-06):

FPGA: Try to respect diff pair for pmod

smunaut, 2020-12-06:
Diff pair on the FPGA are the same as IO site pair.

It wold be nice if the standard way (at least for ice40 fpga board and ulx3s and others ...) was met.
This means on the PMOD side:
 * 3 / 7
 * 2 / 6
 * 1 / 5
 * 0 / 4

And on the FPGA side it would be those pairs:
 * `IOB_2a` / `IOB_3b`
 * `IOB_4a` / `IOB_5b`
 * `IOB_8a` / `IOB_9b`
 * `IOB_0a` / `IOB_6a`  (this isn't a diff pair, or an IO pair but just the 2 other isolated IO site in that bank ...)

Preferably use `IOB_0a` / `IOB_6a`  for the 3/7 pair, mostly for compatibility with icebreaker-bitsy pmod adapter pinout and PMODs designed for it. Also if possible keep the `a` (which is positive diff pair) on the `0/1/2/3` side of the pmod.

renzenicolai, 2020-12-07:
Any chance you might be able to move the pins on the FPGA schematic around a bit, then do a PR?

smunaut, 2020-12-07:
Sure I can give it a shot. I won't get to it until the week end though.
Should I ping you here ?

renzenicolai, 2020-12-07:
yes please, I will try to fix most of the other issues before then

smunaut, 2020-12-12:
I was planning on working on this tomorrow morning if that's good for you ?

renzenicolai, 2020-12-12:
Yes, tomorrow morning works. Just now I've just pushed the fix for some of the reported issues, I will now leave the project alone until after you're done fixing the FPGA pinout.

Thank you very much for taking the time to improve this badge!

smunaut, 2020-12-13:
This is what I ended up with.

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

Comments:
* I renamed the PMOD pins to follow the official naming (1 -> 4, 7 -> 10).
* `PMOD_10i` and `PMOD_4i` can be swapped for routing ease if needed
* The PMOD connector should be moved to the top rather than the bottom (and possibly to the side then if there isn't enough spcace on the bade top edge). A lot of PMOD with user interaction (button screens) need to have the "right side up" to work. I selected the pinout to try and make routing "easier".  Although it's still not great because Lattice pinout/padframe sucks and they didn't put pins in a single io site/diff pair next to each other :/

renzenicolai, 2020-12-13:
thank you :smile:

Closed 2020-12-13.

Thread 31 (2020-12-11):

I2C pullup resistances too high

martinling, 2020-12-11:
The pullup resistors on `I2C_SCL` and `I2C_SDA` are currently 10kΩ. My gut feeling is this that this is too high - but let me justify that quantitatively rather than asking you to trust my judgement:

The rise time of I2C signals results from the combination of the pullup resistance and the bus capacitance; so the pullup resistance must be low enough to meet timing requirements, given the worst-case value for the bus capacitance.

There are 5 devices on the bus:

ESP32 (2pF I/O pin capacitance)
STM32F103 (5pF I/O pin capacitance)
PCA9555 (max 10pF I/O pin capacitance)
BNO055 (unspecified - assume max 10pF)
BME680 (unspecified - assume max 10pF)

That gives a total of 37pF on each line, before even considering other sources e.g. parasitic capacitance of the PCB traces.

There's also a Qwiic connector for adding external I2C devices, which would add further capacitance (both from the devices themselves, and the parasitics of the connectors and cables used to connect them). So the worst-case capacitance could get quite high.

The I2C specification is here: https://www.nxp.com/docs/en/user-guide/UM10204.pdf

At 400kHz, the maximum permitted rise time (`t_r`) is 300ns (Table 10). The equation for maximum pullup resistance is given in section 7.1 as: `R_p_max = t_r / (0.8473 * C_b)` where `C_b` is the bus capacitance.

Taking just the known 37pF capacitances above - which already excludes any parasitics - gives us a maximum pullup resistance of `300e-9 / (0.8473 * 37e-12)` = 9569 Ω. So the value of 10kΩ is definitely too high.

Reducing the pullups to 4.7kΩ would allow for up to 75pF bus capacitance, which would provide some overhead.

Personally I would go lower still - if the timings are only barely met then any interference coupled onto the bus, particularly with external wiring, can more easily cause problems.

renzenicolai, 2020-12-12:
Changed to 4k7 for now, we can always experiment after receiving the prototype as replacing these resistors is easy.

Closed 2020-12-12.

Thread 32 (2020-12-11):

EMC considerations

martinling, 2020-12-11:
Hi, I'm that weirdo from the EMF badge team who cares about EMC.

So you may think this doesn't matter because it's just a camp badge, not a product you're trying to get tested & certified. But I think it's worth trying to get the basics right, and I'll explain why - along with some really simple & cheap things you can do to test & improve things.

Looking at the design, I can guess from experience what the main EMC issues will be. You have two switching regulators and they're going to make noise everywhere. The root causes will be at the fundamental frequencies of the switching rate and the ringing of the switch waveform, and you'll see harmonics of both of those running up into the tens or hundreds of MHz.

Actually, if you look at the output of those regulators it will probably look pretty clean, because in a buck topology the inductor and output capacitor form an effective LC filter without any further help. But the big problem isn't on the output side; it's on the input side. The switching noise will flow back into the input supply unimpeded, and the PCB and the battery will then act as an antenna to radiate that noise.

Fortunately, the device is small enough to be a poor antenna at the frequencies that are likely to be involved, so it won't radiate particularly well. Until you plug in the USB cable, that is. Now you have a great antenna, that's a couple of metres long, and it's going to radiate common mode currents on it quite nicely in the VHF range.

Worse still, the lower frequencies are going to conduct back through the USB cable into the mains, and at camp, that's a bunch of wires strung around a field, which are going to make a decent HF antenna right down into the low MHz range.

So you've got a wideband noise source, which is going to be plugged in every evening to a very effective antenna system. And even if the noise power is small, if you multiply it by 3000 badges, that's equivalent to attaching it to an RF amplifier with a 35dB gain. It can make a big mess all over the radio spectrum, and although it might be hard to spot any particular problem as a result of that, it contributes to making a lot of things work poorly for everybody - particularly all the ham radio operators and other RF nerds at the camp.

So here's a list of what you can do to fix this, highest priority first:

- [x] Add a common mode choke on the USB power lines. For the EMF badge we have part WCM3225F2SF-102T15.
- [x] Add a common mode choke on the USB data lines. For the EMF badge we have part MCE1012E900FBP.

These will reduce common mode currents getting onto the USB cable, where they can radiate. They won't affect the normal flow of power and data since those are both balanced, differential mode currents. To add the choke to the power lines you will need to create a separate ground around the USB connector, and connect this to the system ground only through the choke. The chokes should be as close as possible to the connector, but not closer than the USBLC6-4 TVS array.

- [x] Add footprints for RC snubbers around the switch nodes.

One of the root sources of the noise will be ringing of the switch waveform. You can kill this off at the source by adding a series R-C pair in parallel with each switch. On the SY8079 there are two switches - one between VIN and SW, and one between SW and GND. So add an R and C in series between VIN and SW, and also between SW and GND. The values can be tuned empirically by trial and error while looking at the switch waveform on a scope. Here's a good app note on the technique:
http://rohmfs.rohm.com/en/products/databook/applinote/ic/power/switching_regulator/buck_snubber_app-e.pdf

- [x] Add an LC filter at the input of each switching regulator.

This will help attenuate the switch noise propagating back into the power supply. A shunt capacitor of a few uF, plus a series inductor of a couple of uH, should do the trick. At least put the footprints in - you can always fill the L with an 0 ohm resistor and leave out the cap, if you don't need them.

There are more things you can do to optimise things further if you want to, but the above points are what I'd expect to make the biggest differences for this design.

If you get the necessary footprints included then I'm happy to help with testing and tuning if you can ship me a prototype board. You don't need an EMC lab - everything needed can be done on the bench with a scope, a basic SDR if you don't have a spectrum analyser, and some homemade probes.

zoe1337, 2020-12-11:
I haven't tested this particular Silergy converter, but I was doing design validation of low power DC/DC converters and I don't think this 1-MHz converter is of particular concern.

> One of the root sources of the noise will be ringing of the switch waveform.

This "ringing on switch node" is virtually nonexistent at these power levels. Since the FETs are small and are on the same die, the parasitics are negligible. See waveform cropped from datasheet:
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

The switch node indeed has high dV/dt and it should be minimized, but with proper PCB layout it is a very small antenna. An RC snubber is absolutely unnecessary, and would only ruin efficiency.

You are correct that input current is discontinuous, and that's what the input capacitor is meant to help with. To suppress higher frequency harmonics, a 100-nF 0402 MLCC parallel to the 22-uF C4 cap is a good idea.

This noise is, however, differential mode, and a CM choke would do nothing to suppress it. Luckily, it only forms a loop antenna of a very small surface, just between the VBUS and GND lines. With shielded cables this is not a concern at all, and with some luck you might pass the legal EMI limits without further action. The input MLCCs are excellent at suppressing switching harmonics, especially if low ESL (small footprint) additional decoupling is added, as recommended in my previous paragraph.

That said, if so desired, another 22-uF MLCC can help, at little expense. Should a differential mode ferrite bead necessary, that needs to have rather high inductance and low enough DCR, so it doesn't come at a large tradeoff. Something like NFZ32BW210HN11L (22 Ohm at 1 MHz) or NFZ32BW6R8HN11L (6.8 Ohm at 1 MHz), from Murata, both available at LCSC. These eat into the efficiency of the converter thanks to the additional ohmic losses in the power path, also, these might require even more input capacitance, and could require turn-on voltage slope control to avoid potentially destructive excessive ringing from inrush current.

Adding a common mode choke on the USB data lines is a good idea for unrelated reasons.

martinling, 2020-12-11:
I'm not sure you can rely on that datasheet plot to say what the edges on the switch waveform will really look like. Often if you probe a switch node with a scope probe with the usual ground cable, it looks okay at first because the inductance of the ground wire is effectively filtering out the higher frequencies. But if you take off the ground cable and use a short wire wrapped around the probe shield (as in Figure 6 in the Rohm app note above), the bandwidth of the probe setup increases and suddenly the picture can actually look very different, especially close up in the corner of the waveform.

You may be right that the small FETs make the issue negligible - and if there indeed isn't any ringing on the switch waveform then of course you don't need the snubbing. But I would certainly test it to be sure, and my suggestion is to include the RC footprints at the prototype stage, so that it's possible to snub a bit if needed; you can always leave them unpopulated, and remove at the next board iteration if not used. A little bit of snubbing doesn't have to ruin efficiency - it will always decrease it, but adjusting the RC values allows for a continuous tradeoff between efficiency and noise, and often it only costs a negligible % or two in efficiency to clean things up a lot.
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
renzenicolai, 2020-12-12:
Thank you for the suggestions!

Would you, by any chance, have Kicad symbols / footprints for the WCM3225F2SF-102T15 and MCE1012E900FBP parts?

martinling, 2020-12-13:
Sure, see #33.

For WCM3225F2SF-102T15 you can use the `L_Core_Ferrite_Coupled` symbol from the Kicad standard library. For MCE1012E900FBP, use the `L_Core_Ferrite_Coupled_Small_GND` symbol included in #33 with the footprints.

renzenicolai, 2020-12-18:
I've added the chokes around the usb connector. How would you recommend me to connect the shielding of the usb connector?

martinling, 2020-12-20:
> How would you recommend me to connect the shielding of the usb connector?

That's a great question for which I really just don't have a firm answer, I'm afraid - there are various flame wars you can read on the topic if you want to make your head hurt.

The basic issue as I see it is that for a board without a metal housing there's no great solution for what to do with the shield at the device end. It's a matter of balancing different considerations with opposing needs - for transients and noise immunity you tend to want minimum impedance from the shield to ground, because it's exposed to the environment and you want to short away everything that might couple onto it as firmly as possible. But that conflicts with minimising emissions - you want to avoid noise from your system ground getting out onto the shield, so you want some impedance in the way of it getting there.

Your basic options are:

1. Don't connect the shield at all.
2. Connect the shield directly to ground.
3. Connect the shield to ground through a capacitor and resistor in parallel.
4. Connect the shield to ground through a ferrite bead.

Each optimises for different things. Usually I hedge my bets and put a couple of footprints to GND, so that if the board fails EMC testing I have some options to try.

renzenicolai, 2020-12-21:
I'm going to connect both usb shield and usb gnd directly to my device ground, which will be a big copper fill on one of the layers.
In turn the USB power line will have a ferrite core in it's path, to at least limit the noise.

renzenicolai, 2020-12-21:
I've added an extra resistor in series between vin and the each of the regulators, together with a second capacitor at the input of the regulators. This should allow for implementing a low pass filter if needed.

martinling, 2020-12-22:
The ferrite & extra footprints for filtering at the regulators seem like a reasonable set of precautions against differential mode noise getting onto the USB power lines, which from an emissions perspective basically addresses conducted emissions at the lower frequency (< 30MHz) end of things.

I would still be worried about higher frequency common mode noise on the USB power lines, leading to radiated emissions directly from the cable in VHF & above, which the ferrite won't really help you with.

Common mode noise will be generated from ground/power bounce, on both the switching regulators and from switching currents in the FPGA & other digital parts, as well as poor return paths (i.e. large loop areas) for signals. So you'll see it at clock & switching frequencies and harmonics of them. You can minimise this by good layout and power distribution though, so if you're confident in getting that right, you may be okay to leave out the common mode choke. Personally I'd keep the footprint for it in as an option until able to test.

renzenicolai, 2021-01-11:
We've done what we can here I think. If you have suggestions for the current state of the project please open a new issue :smile:

Closed 2021-01-11.

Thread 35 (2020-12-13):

Comments on the board routing

smunaut, 2020-12-13:
While reviewing and fixing some of the schematics, I had a glance at the current layout (obviously not finished ..) around the FPGA and I had a few comments :

* The 100n decoupling caps need to be near the pins they protect (one per pin), not across the chip. `0603` is definitely a bit big, if moving to `0402` would make that easier. But then again, this is also already a dual load board so putting the decoupling on the other side of the chip would make things pretty trivial.

* Also, power pins and associate decoupling should have their own non-shared vias, with large trace to those via (pretty much the width of the pad/via).

* Length matching: This is not required. None of the signals on this board go anywhere fast enough to warrant it. If anything it actually hurt things. For instance the traces to the PMOD would be better served by being routed as pairs, short and close together than the random serpentine that's currently there.

renzenicolai, 2021-01-11:
Fixed.

Closed 2021-01-11.

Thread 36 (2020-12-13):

Resistors as signal combiners have issues

Wilenzo, 2020-12-13:
In the schematic I see a few 47 Ohm signal combiner solutions, this is not really a good idea imho. For each time both inputs have a different state it draws about 33mA at 3.3V

It's better to use diode logic for this: https://i.stack.imgur.com/ntAAj.gif

Whether you go for the AND or OR solution depends on the chips driving it: Do you normally have an active low or high state when it's doing nothing or do you have (internal) pull-ups/downs connected is mainly what makes you go for AND or OR.

The resistor must be chosen small enough so the slew-rate of the signal is sharp enough. It depends mostly on the input capacitance of the chip connected to the output of the diode gate combined with the diode capacitance and stray capacitance of the traces on the PCB. Put the logic close to the chip that's driven by the diode gate.

I've found the questionable resistor solutions on page 1 near the PCM5100, page 3, R19 & R20 (and R18 could even mean more than 66mA being wasted) and on page 4.

smunaut, 2020-12-18:
IMHO this is worse than resistors ...

Resistors only have high current when you screw up and drive from both side. It's a protection measure. Using diode logic means that 100% of the time you rely on a resistor for one of your edge and you're fighting that resistor when trying to drive the other state.

So you're increasing drastically power consumption during _normal_ operation while for the resistors, this only happens during contention / i.e. when you screw up and try to drive from both devices at once.

Wilenzo, 2020-12-18:
I agree it is not a perfect solution, a single logic gate would be much better. But using resistors this way is asking for problems.

The resistor solution is just not done because it could destroy chips that drive this contraption (excess pin current or even Vss/Vdd current if more pins are involved), it could destroy the chip that's being driven (signals midway between logic 0 and 1 can lead to destruction), and all that current draw can maybe lead to a bricked badge that is stuck in some brown-out loop or it could even lead to smoking components. And with resistors, a lot more EMI is generated because the trace to the chip that is in tri-state mode is driven hard by the other chip. With the diode solution this is much less of an issue.

Remember: User screw-ups are very common on prototyping boards and should be non destructive! The FPGA can only sink/source 8mA on its pins, with the resistors it is limited to 33/66mA... Almost 4 or 8 times too high! And if a user screws up, it might not become clear what the problem is because so many things are involved. Even with an oscilloscope it might not be very clear if you don't look closely at the voltage levels as the waveform stays intact.

The resistor in the diode configuration does not have to be a huge power consumer. It will probably be in the order of 5k for signals up to about 10MHz at 10pF load. (8pf for the input +2*1pF for the diodes, type: BAS16) But it's better to aim a bit lower, 3k3 should work nicely. With a 50% duty cycle signal this consumes 0.5mA at 3.3V. If the signals are 10% or 90% duty cycle it only consumes 0.1mA if the inactive state and the type of logic combination is chosen wisely. For high speed signals, lower the resistance or use logic gates.

smunaut, 2020-12-18:
(1) Not sure how you do your math but 5k with 10pF load has a 3 dB cut-off of 3.2 MHz. And you want your signal to remain "squarish" so at most I'd put 3dB f_c at the 5th harmonic. So for a 10 pF load, your resistor value is like 300 ohm to get a decent edge at 10 MHz.

(2) EMI: The high current to fight that resistor are going to generate much more of a field than the small amount needed to charge/discharge the trace, even if the effective antenna length is doubled.

(3) The FPGA can drive/sink way more than 8 mA, that's just the max value for which its Vol/Voh and transitions times meet the specs.  I've caracterized the UP5k drivers ( part of the results : https://github.com/YosysHQ/icestorm/wiki/UP5k-Driver-Characteristics ) and among the test were driving the IO directly shorted to the rail for long period with no ill effects. Heck, we've even fed 3v3 to the 1v2 rail of that chip and it took it without dying ...

(4) Drivers are not perfect, the one from the UP5k are ~ 50ohm impedance, not sure about the other side, but even if they're damn strong they'd be like 25 ohm. In another issue it was recommended to bump 47R to 68R. So that'd be 3.3v into 211 ohm which is only 15 mA worst case for a persitent conflict. That's not going to kill any decent cmos driver.

(5) The diode logic also kills some use case. For instance, Imagine you want to use the PMOD port with the HDMI PMOD to transmit image and sound ... well now the fpga can no longer passively listen to the sound transmitted by the other chip to encode it on HDMI.  Or to generate an equalizer display from the music or whatever ...

Wilenzo, 2020-12-19:
(1) 300 Ohm is a good idea if you have asynchronous signals that need a certain steady state bit length or when you have some hard wired signals you need to be (almost) in sync with, but for clocked signals that accept a far from 50/50 duty cycle on the clock and were signals all go through the same type of diode logic, 3k3 is still fine in most cases. I've used something like this before without problems. With 5k on 10pF it takes 50ns to reach 63.2% of the voltage level, for most CMOS signals it works, but it's 70% you'll officially need to flip the state, so that's why I was aiming at 3k3 or lower for this. But signals will be spiky, true.

(2) True, didn't think of that. Although it might not be just as straightforward as the floating pin and trace add a lot of capacitance. The diode reverse capacitance is less than a pF while the floating trace and pin will double the drive current too due to added capacitance and the length/area of the "antenna" is doubled too. So it's not a simple manner of just current through the resistor.

(3) Ok, didn't know, but still, going beyond specs is a thing I would never recommend.

(4) What about using just, let's say a 150Ohm, resistor on one of the driving chips and the other one hardwired? This way, one chip always has the overhand when things collide, so no mid VCC voltages on the lines. And it makes for a much better to trace fault without much side effects. It saves a resistor too and it does not make me want to vomit as much as the two resistor solution.

(5) True, might even be a useful case too!

renzenicolai, 2020-12-21:
Changed resistor combinations with one higher value resistor and a short, so that one device has priority.

smunaut, 2020-12-21:
:(

smunaut, 2020-12-21:
(1) Having inline resistor to take the edge off is always nice to avoid excessive ringing (also helps EMI).

(2) When the user does something wrong, it *SHOULD* fail, that's how the user will know something is wrong. Here, he might be stressing the drivers of one of the device not for minutes to hours, but potentially for days, weeks because he will never know something is wrong since "it works" ...

Wilenzo, 2020-12-22:
(1) Most of the other lines don't have resistors in series anyways, plus the impedance of the drivers themselves already takes care of ringing.

(2) It is NEVER a good idea to have logic fail on half the logic voltage level. This could DESTROY input circuitry of components. That's why you never see this construction in final designs, unless maybe when all of the inputs have schmitt-trigger functionality. But I do agree there is in half of the cases no feedback to the user now, that's a pity, but a mention in the docs and example code should be more than enough of a warning.

Closed 2020-12-21.

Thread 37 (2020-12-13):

Capacitors near crystals

Wilenzo, 2020-12-13:
I don't know if all are calculated to be 22p, but if it's not the case, read this: https://blog.adafruit.com/2012/01/24/choosing-the-right-crystal-and-caps-for-your-design/

renzenicolai, 2021-01-11:
Thank you, we will keep this in mind.

Closed 2021-01-11.

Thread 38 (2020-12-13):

PWR_LED also on U10?

Wilenzo, 2020-12-13:
The LEDs can be damaged if U5 is in over-current mode and the LED data pin is being driven high. Power to U10 should also be connected to PWR_LED. The input of U10 should have a diode AND gate with a pull-up to PWR_LED so U10 is protected as well.

renzenicolai, 2020-12-18:
Change made: U10 is now powered by PWR_LED.

The datasheet for U10 (74LVC1G125) seems to suggest that it can't be damaged by an input voltage that's higher than the supply voltage, could you also have a look at (table 6 of) the datasheet? I'd have expected Vi to be expressed in "0 to vcc+0.5v" terms or the like if there was a risk of damaging the IC, but it states "0 to 5.5v", so regardless of Vcc it can handle 5.5v on the Vi pin.

Wilenzo, 2020-12-18:
Ah, this chip has no internal diode from input to VCC it seems, this allows for 5 to 3V level conversion. So it probably will be ok.

Closed 2020-12-18.

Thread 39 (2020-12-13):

Just a concern: I2C pullups

Wilenzo, 2020-12-13:
I don't know if FM(+) or HS is being used for I2C, but even when it's not, with a fair amount of I2C devices on the bus you should calculate the pull-up resistors: https://www.ti.com/lit/an/slva689/slva689.pdf?ts=1607836778518

martinling, 2020-12-19:
I did some calculations on this - see #31.

renzenicolai, 2020-12-20:
Good point, closing as duplicate of #31

Closed 2020-12-20.

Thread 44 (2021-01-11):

Prototyping area

renzenicolai, 2021-01-11:
- Make sure footprints are referenced from schematic
 - Add labels to pins
 - Add pins to second prototyping area
 - Expand hardware hacking area

renzenicolai, 2021-01-11:
Footprints are referenced now

Closed 2021-01-11.

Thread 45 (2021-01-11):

Headphone output

smunaut, 2021-01-11:
The PCM5100 doesn't have any output amplifying stage. It's meant to drive high input impedance line loads, datasheet list 1kOhm as min load impedance and 10 kOhms as recommended one.

A typical headphone is 32 Ohms ... very very far from high impedance, there needs to be a headphone amplifier stage if that TRS jack is meant as a headphone output.

Closed 2022-04-02.

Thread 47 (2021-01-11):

PMOD on top (or pinout such that pmod plug "right side up")

smunaut, 2021-01-11:
It's a comment I made on another issue, but not sure if this was considered.

Quite a few PMODs have "user interaction" elements (LED / button / screen / ...), and having the PMOD such that it is now, those would face toward the back ...

I would recommend either put the connector on the top of the badge, or, if for aestetic reason the actual connector has to be on the back, adapt the pinout so that PMODs are plugged with the right side up.

( Technically by putting 'GND' and '3v3' columns on each side you can even make it so that pmods can be plugged both way, assuming the user aligns it properly ... since it's a fpga, remapping pins is not an issue.  Not sure I'd recommend it though since it might be confusing )

sebastius, 2021-01-11:
The trouble we'll have anyway is that the PMOD connectors will be soldered by the visitors, so we need to make sure to have clear instructions on the board on what is what and how to mount it.

renzenicolai, 2021-01-12:
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

Viewed from the bottom of the PCB, connector is placed on the bottom side.

Is this good enough?

smunaut, 2021-01-12:
Electrically yeah, that looks good to me.

The silk doesn't follow the standard PMOD notation however. In the digilent pmod specs and usual labels, the pins are 1,2,3,4,7,8,9,10  and not 0-7.

And I would also add a note like "PMOD top side toward screen" or something like that.

renzenicolai, 2021-01-14:
Numbering has been changed.

Closed 2021-01-14.

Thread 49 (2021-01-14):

3.3V switching converter layout

martinling, 2021-01-14:
A few thoughts on this section:

 1. All the supply current for the 3.3V converter has to pass through this one little 0.2mm trace - make it thicker!

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

 2. I'd suggest moving C35 so that it's closer to U11 than C38. The idea (from #32) was to be able to put a smaller value capacitor there which would provide lower impedance at higher frequencies than the bulk capacitor. For that plan to work well, the smaller cap should be closer to the load, with the smallest possible loop area.

 3. I'd suggest rotating L3 90 degrees to put its pin 2 closer to U11 pin 3, to minimise the area of the SW33 net as much as possible. The smaller you can make it the less it can radiate.

 4. Personally I would thicken up the grounding around this section a lot - use  a polygon fill around the ground pins of the bulk capacitors, add more vias from there to the groundplane beneath, and add turn the ground ring around the whole section into a via fence. Similarly, you can put a polygon around the 3.3V pins of the inductor, the output caps, and the vias to the 3.3V plane.

Most of these points are also applicable to the 1.2V converter section.

kliment, 2021-01-14:
I'm on this

kliment, 2021-01-14:
Implemented mostly as suggested for both converters.

Closed 2021-01-14.

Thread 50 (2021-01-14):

Long VIN trace with poor return path - likely EMI issue

martinling, 2021-01-14:
Most of the layout looks reasonable from an EMC point of view - the high speed stuff is mostly on the back side with a continuous ground plane directly under it.

What struck me as a problem is this long VIN trace, which I think is at risk of causing some radiated emissions:

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

It will have high frequency noise on it, potentially at quite high currents, because it's providing the input supply to both switching converters.

It's long enough to make a decent antenna.

And it doesn't have a good return path - VIN is referenced to GND, but the plane directly under the trace is at 3.3V. The GND plane further below it is a lot further away (assuming typical 4-layer stackup) and high frequency currents will try to stick close to the trace. They'll end up the using 3.3V plane beneath as the return path to the extent they can, but there's two slots in that plane near U5. There's also another gap in the return path where it cuts a corner through the antenna keepout zone in the top left of the board.

Can you avoid needing such a long trace? Or arrange to have it run over a continuous ground plane?

kliment, 2021-01-14:
We can't avoid it because we need to supply power to the LEDs in the top corner and the source of the power is either battery or USB, which are on bottom edge. I might be able to manage continuous ground but then it would have to run along the other side and be even longer. The 1V2 supply is placed to minimize vin trace length, whereas the 3V3 supply is placed exactly between its two highest-current users. I'll see what I can do. Do you have any recommendations?

kliment, 2021-01-14:
Solution: make long trace longer, give it continuous return path immediately below.

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

martinling, 2021-01-14:
That looks better to me, although I'm a bit wary of having a noisy high current trace running along a board edge as you have at the top there - I try to keep some ground all the way around the outside of a board and tie the ground fills with vias there too.

What I was just writing before you posted that, is that if you can't change the basic arrangement then I suggest to add some small capacitors (say 10nF) between 3.3V and GND, with adjacent vias to the 3.3V/GND planes, at the following places:
  1. At the ends of the trace.
  2. At points in the middle where loads are connected.
  3. On either side of any breaks in the 3.3V plane under the trace.

That would allow high frequency currents to use the 3.3V plane as a a return path.

My other thought was that LC filters at the switcher inputs would help keep noise off the trace in the first place.

kliment, 2021-01-14:
I added ground all the way around the trace along the edges. There's also a groundplane on the layer immediately below everywhere except a tiny bit at the top left corner.

renzenicolai, 2021-01-14:
Hello y'all, I'd like to see a solution that doesn't affect the looks of the badge as much. This new trace you made is clearly visible to the user unfortunately. Is there a way to hide it a bit more?

martinling, 2021-01-14:
@renzenicolai, was it OK visually where it was before? You could leave it there (but clean up the corner in the top left) and add the capacitors discussed above to improve the high frequency return path. Using the 3.3V plane as a return path will add some noise onto the 3.3V supply, but I don't think you have any particularly critical analog stuff on that rail - the IMU sensors and the audio codec do some internal regulation IIRC.

@kliment I wouldn't worry too much about minimising the length specifically - what matters is the loop area. As long as the return path is close (and getting it on the adjacent layer makes it like 5x closer for a typical stackup) then the loop area is small even if the trace is long.

martinling, 2021-01-14:
Just seen the new version - looks good to me now.

Closed 2021-01-14.

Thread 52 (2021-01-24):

[footprint] SK6805-15 pin numbering

renzenicolai, 2021-01-24:
The pin numbering doesn't match the layout as described on
http://www.normandled.com/Product/view/id/842.html

renzenicolai, 2021-01-24:
Pin order is correct though, so soldering them the right way round should result in a working led when MANUALLY assembled.

Fix this before production and provide clear instructions for the assembly people.

renzenicolai, 2021-11-14:
Fixed

Closed 2021-11-14.

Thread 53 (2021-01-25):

SK6805-EC15 wrong label in schematic

renzenicolai, 2021-01-25:
For some reason it's labeled SK6812-EC15, this is wrong.

renzenicolai, 2021-10-08:
Label changed

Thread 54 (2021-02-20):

Ground connections J7 and U8

sebastius, 2021-02-20:
Footprints should have no ground connections between the pins, it hurts soldering/reflow. Branch out with a comb and use keepout on the gnd-fill.

U8 should not have gnd plane underneath the chip, it will desorient the compass.

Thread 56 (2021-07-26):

STM32 BOOT0 pulled high by PCA9555

renzenicolai, 2021-07-26:
The PCA9555 has a built-in pullup which causes the BOOT0 pin to be high even though there is a pull-down resistor on the board.

Solution: tie BOOT0 low permanently and use a software based bootloader entry function instead.

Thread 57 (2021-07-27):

STM32 USB circuit

renzenicolai, 2021-07-27:
- 22 ohm resistors in series with D+ and D-
 - 4k7 ohm pull-up on D+ (on the STM32 side of the 22 ohm resistor)
 - Soldering pads for bypassing the choke (which is way too small to hand solder)

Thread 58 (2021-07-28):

MCE1012E900FBP (USB ferrite coupled core) not recommended for new designs

renzenicolai, 2021-07-28:
Component L2 needs to be replaced.

renzenicolai, 2021-10-09:
Removed L2 completely, it's a limited run devboard, not a consumer product so these extras are pure overkill.

Closed 2021-10-09.

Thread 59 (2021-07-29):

Connect SD power enable directly to ESP32

renzenicolai, 2021-07-29:
Connecting it to the STM32 was a stupid idea, when the ESP32 crashes it doesn't start again when the SD card is still enabled.

Can be fixed by removing led data out from the esp32 and putting sd power there.

renzenicolai, 2021-08-06:
Also: just directly connect the STM32 to LED data.

renzenicolai, 2021-10-08:
Fixed, STM32 pin is now connected to a testpoint as it is no longer used. ESP32 pin is routed to SD card power enable.

Closed 2021-10-08.

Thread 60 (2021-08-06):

FPGA LED pin numbering is wrong

renzenicolai, 2021-08-06:
The pin numbering of the FPGA LED (D2) is completely wrong, also the pin 1 indication is missing from silkscreen.

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

renzenicolai, 2021-11-14:
Fixed

Closed 2021-11-14.

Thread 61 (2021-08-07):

Bosch BNO055 and the STM32 can't share the boot pin

renzenicolai, 2021-08-07:
STM32 needs a pull-down, BNO055 needs a pull-up on the same line.

Solution: disconnect the BNO055 boot pin from the controlled line and leave a testpad for manual bootloader triggering.

renzenicolai, 2021-10-09:
Fixed by disconnecting the BNO055 boot pin from the STM32 bootpin (leaving only a testpad to control the BNO055 bootpin).

The pull-up of the BNO055 pin is left as is, the pull-down of the STM32 bootpin has been moved.

Closed 2021-10-09.

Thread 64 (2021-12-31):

[Prototype 2] Badge doesn't work when using battery power

renzenicolai, 2021-12-31:
Leakage through D9 causes VUSB to raise to +/- 1.5 volt, this causes Q4 to open partially, pulling the enable pin of U14 half way down.

This causes U14 to not fully open, solution: remove Q4. The SY6280AAC prevents backflow of current and the USB supply voltage through D9 pulls the voltage at the output of U14 higher than the input voltage from the battery so there won't be any current flow from the battery either way.

This also applies to prototype 3.2

renzenicolai, 2021-12-31:
Also the current limit set by R63 is weird: it's set to 680mA, which is way too little considering that the LED power rail is limited at 2A.

Logical solution: set current limit when running on battery to 2A, change value of R63 to 3.4kOhm

renzenicolai, 2022-01-14:
I will make a separate issue for the battery power limit

Closed 2022-01-14.

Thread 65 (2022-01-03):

[Prototype 3] Value of R24 is wrong

renzenicolai, 2022-01-03:
Increase to 1k Ohms (currently at 47 ohms)

renzenicolai, 2022-01-14:
Fixed in prototype 4

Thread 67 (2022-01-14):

Battery power limit

renzenicolai, 2022-01-14:
The current limit set by R63 is weird: it's set to 680mA, which is way too little considering that the LED power rail is limited at 2A.

Logical solution: set current limit when running on battery to 2A, change value of R63 to 3.4kOhm

Closed 2022-03-15.

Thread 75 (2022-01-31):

Get rid of PCA9555

renzenicolai, 2022-01-31:
It has become really expensive, I think we might be able to replace it by using GPIO pins on the RP2040.

SPI slave can be removed (4 pins)
Select button can be connected to bootsel

Closed 2022-03-11.

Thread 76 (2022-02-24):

Add hardware RESET button

robotman2412, 2022-02-24:
It's very inconvenient not to have one and then to have to reconnect the power.

renzenicolai, 2022-04-02:
Added a reset button for the RP2040, hitting that also resets the ESP32. ESP32 can be reset using esptool.py as well.

Closed 2022-04-02.

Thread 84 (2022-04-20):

I2S LR and SCK swapped

renzenicolai, 2022-04-20:
See main sheet, needs a small fix to the schematic

Closed 2022-04-23.

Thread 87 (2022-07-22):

Direction of LCD_MODE net label is wrong direction in PDF

cyber-murmel, 2022-07-22:
LCD_MODE is [input](https://github.com/amaranth-lang/amaranth-boards/pull/203#issuecomment-1192541476) as seen from the FPGA

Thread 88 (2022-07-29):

RGB-5050 led datasheet is wrong

xeniter, 2022-07-29:
https://datasheet.lcsc.com/lcsc/1811131122_HONGLITRONIC-Hongli-Zhihui--HONGLITRONIC--HL-AF-5060H271BU46FU79GC-S1-THL_C219409.pdf

is wrong, also schematic, green and blue are swapped, at least with the led on my badge it is:

PIN 4 green and PIN 6 BLUE

renzenicolai, 2023-04-22:
I'm not updating the hardware design as the names in the schematic match the LED in the bill of materials. We did give the sourcing agent some freedom when searching for the cheapest parts to use for production, that's why the LED colors are swapped: the datasheet is right, the schematic is right, it's just a different type of LED...

The documentation for the badge will be updated to reflect the actual LED colors.

Closed 2023-04-22.

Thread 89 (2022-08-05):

Wish: JTAG debug interface

stappersg, 2022-08-05:
Some IRC log, MCH2022 was already over:
```text
17:46 < zgreg> the workflow for getting python apps onto the badge and running
    and debugging them never really worked for me
17:48 < zgreg> but you can't debug native esp32 applications without additional
    hardware, or can you?
17:49 < JulianScheffers> The JTAG is inaccessible unfortunately.
17:49 < JulianScheffers> I usually have to do print debugging.
17:49 < zgreg> that's something that always seemed odd to me about the
    esp8266/esp32 ecosystem. proper interactive debugging was mostly seen as
    something esoteric that isn't really needed...
17:50 < TomClement> zgreg: This is something that became accepted in the Arduino
    era, imo. Luckily for ESP32 there’s a nice JTAG interface you can use,
    although not all projects expose it
```

Now my wish:   The `rp2040` is also a _JTAG probe_.

That wish smaller:   The PCB for a next  _esp32-rp2040-combo_ has wires, copper tracks, that make it possible that the `rp2040` can be used as _JTAG probe_ to connect the `esp32` JTAG interface.

smunaut, 2022-08-05:
The problem is not that the pins/pads are not accessible ... is that every single IO on the ESP32 is used for something, so the JTAG has to be disabled to make room for them.

stappersg, 2022-08-05:
If a JTAG debug interface for current PCB is possible, please say so.  After all for (re)flashing the board is the USB-connector already being used (`rp2040` "talking" to `esp32`).

smunaut, 2022-08-05:
It's not possible ... that's what I said above. And no PCB revision will change that, there is just not enough IO pins on the ESP32 module to have all the functions of the badge _and_ JTAG.

The reflashing doesn't use JTAG at all, it uses the ESP32 rom bootloader and goes through the serial connection.

stappersg, 2022-08-05:
Oops

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

> The reflashing doesn't use JTAG at all, it uses the ESP32 rom bootloader and goes through the serial connection.

Acknowledge on that.

And I admit that I don't know if the _SPI connection_ between the _esp32_ and the _rp2040_ is  20% or 80% of a _JTAG connection_.

smunaut, 2022-08-05:
Huh ?

(1) There is no SPI connections between the ESP32 and RP2040.
(2) I have no clue what you mean by "being 20% or 80% of a JTAG connection"

The only thing the RP2040 can do is basically reset the ESP32 and send the special char through the serial (as in: UART/RS232) link to go to bootloader mode and flash the thing. But obviously in that mode, the bootloader is running, no user code, so you can't use that to debug your code or anything like that.

stappersg, 2022-08-05:
> There is no SPI connections between the ESP32 and RP2040.

I stand corrected, not SPI but I2C. Source, the blockdiagram from https://badge.team/docs/badges/mch2022/hardware/

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

New version of the wish:
In a next  _esp32-rp2040-combo_ is it possible that the `rp2040` can be used as _JTAG probe_ to connect the `esp32` JTAG interface.

a2800276, 2022-08-05:
> it's that every single IO on the ESP32 is used for something

Tragically, that's not the case, there are ~9 unconnected IOs. We really should at least route everything to board edge for future badges...

But the JTAG pins _are_ occupied.

@stappersg you could theoretically cut some traces and use JTAG but that would kill FPGA, SD Card and I2S functionality (12,13,14 are necessary for JTAG, quick dirty google search, may not be correct.)

JTAG is one of few peripheral that can't be mux'ed to other pins, so the rp2040 would also not be able to access those specific pins, i.e. there is no possible firmware fix.

smunaut, 2022-08-05:
What are you talking about ?
What 9 IOs ?

- Pins 17-22 are NC on the ESP32-WROVER-E modules used on the badge (they're used internally for the flash inside the module)
- Pins 27/28 are just NC on that series on module

So I'm not sure where you see 9 unconnected IOs.

a2800276, 2022-08-05:
Wishful thinking :)    You're absolutely correct, I'm used to WROOM, which has a single nc pin. What were they thinking with that module?

smunaut, 2022-08-05:
AFAIU the modules that have those IOs don't have embedded flash ... and then you need to wire up the flash to them so it doesn't give you more IOs, it's just if you want your flash outside the module.

renzenicolai, 2023-04-22:
smunaut is right, ESP32 uses specific pins for JTAG which are NOT connected to the RP2040 on the MCH2022 badge. If you really want to use JTAG on your badge you can find the connection points here:

TDI is GPIO12
TCK is GPIO13
TMS is GPIO14
TDO is GPIO15

GPIO12 is used as I2S left-right clock
GPIO13 is used as I2S data
GPIO14 is used as SD clock
GPIO15 is used as SD CMD

So if your app does not use the audio output and the SD card you can safely ignore those peripherals and use JTAG. The I2S pins are available on testpads but the SD card pins are not so I recommend you connect small wires directly to the pads of the ESP32 module.

Good luck!

Closed 2023-04-22.

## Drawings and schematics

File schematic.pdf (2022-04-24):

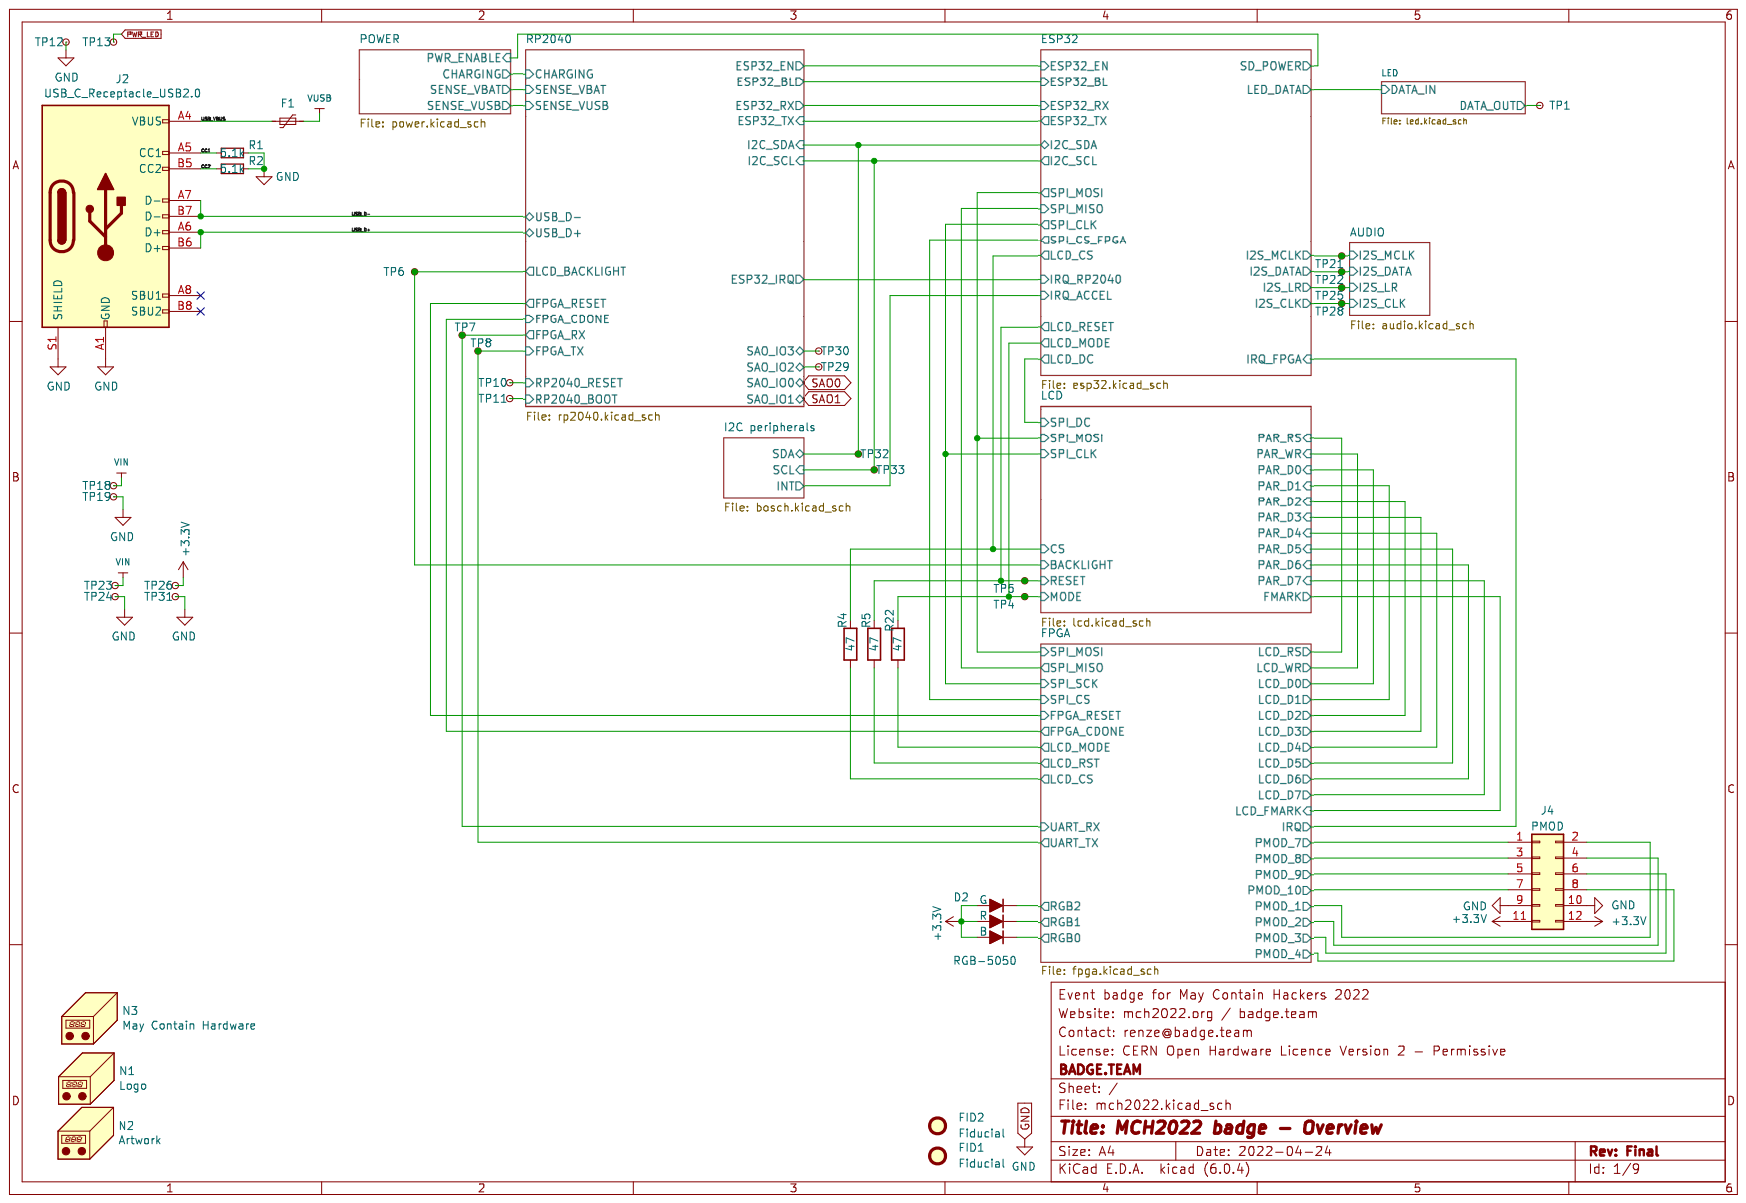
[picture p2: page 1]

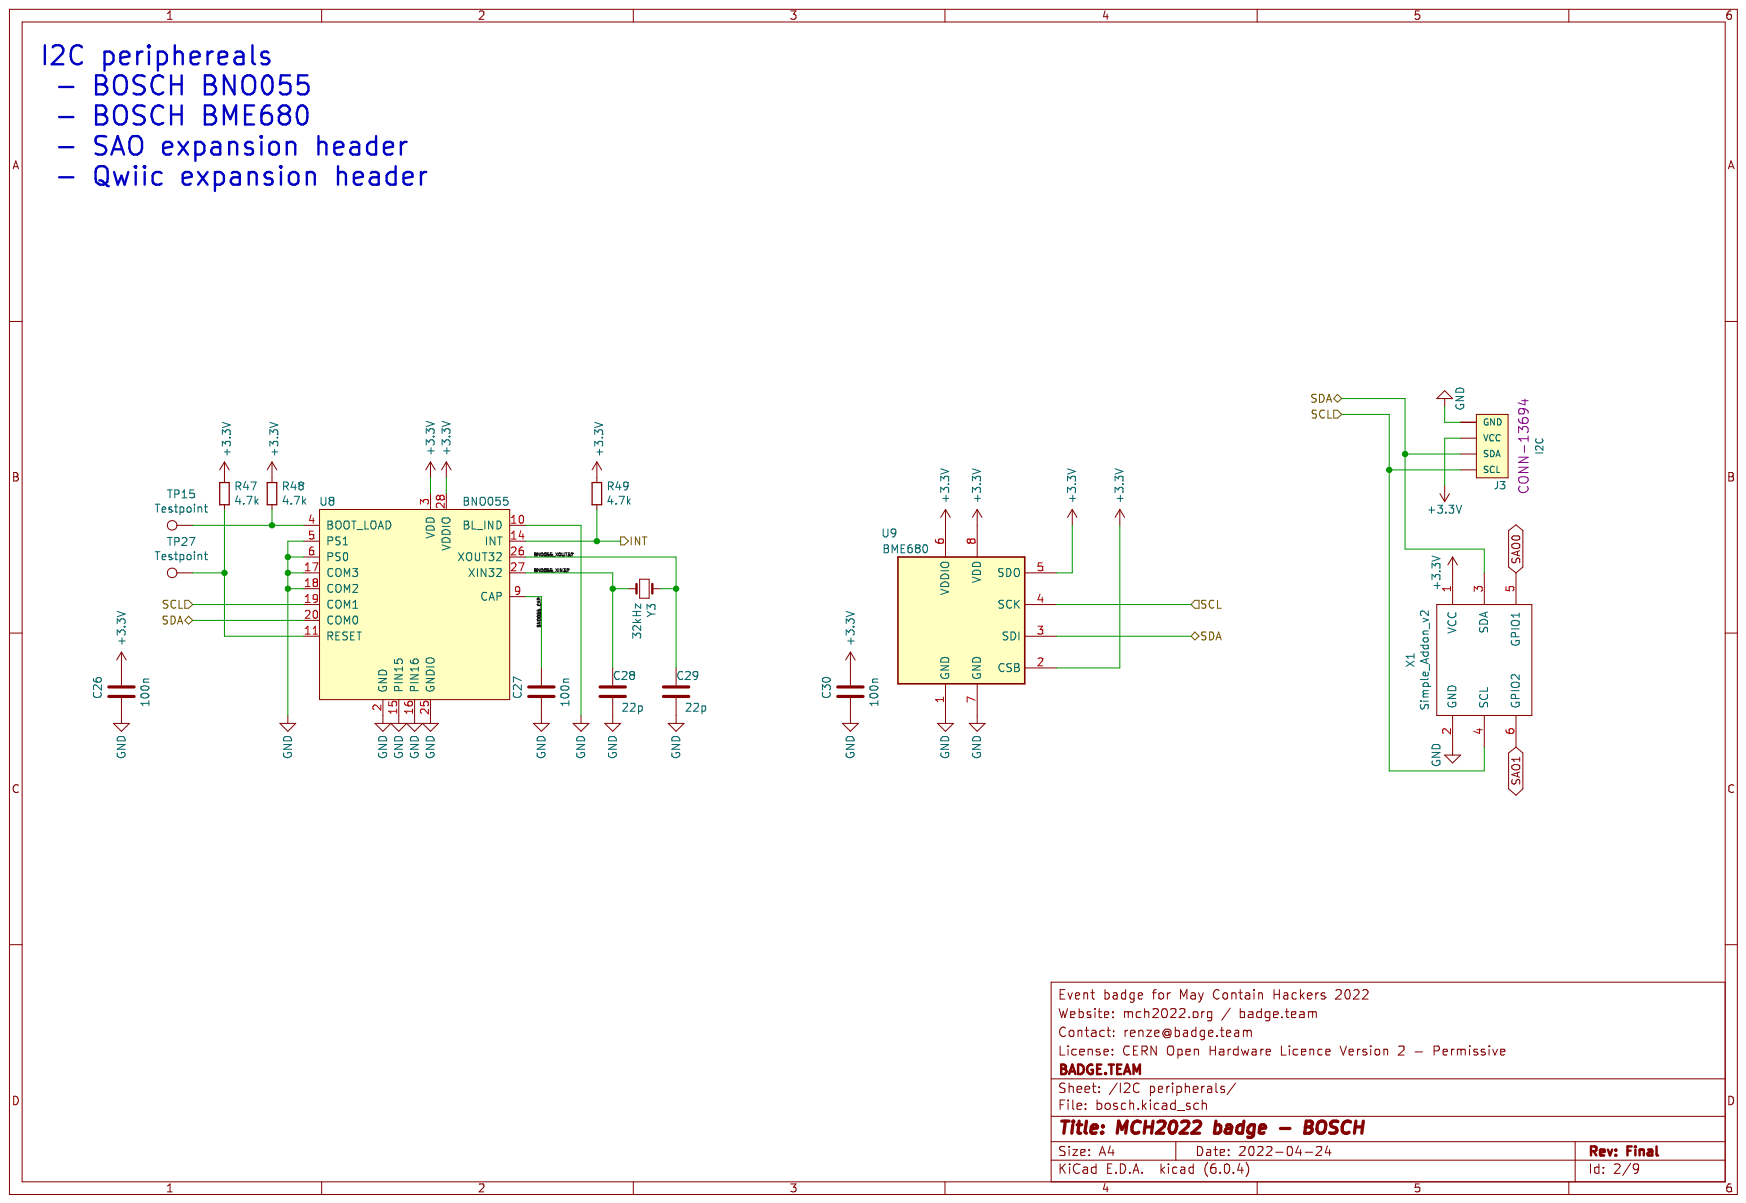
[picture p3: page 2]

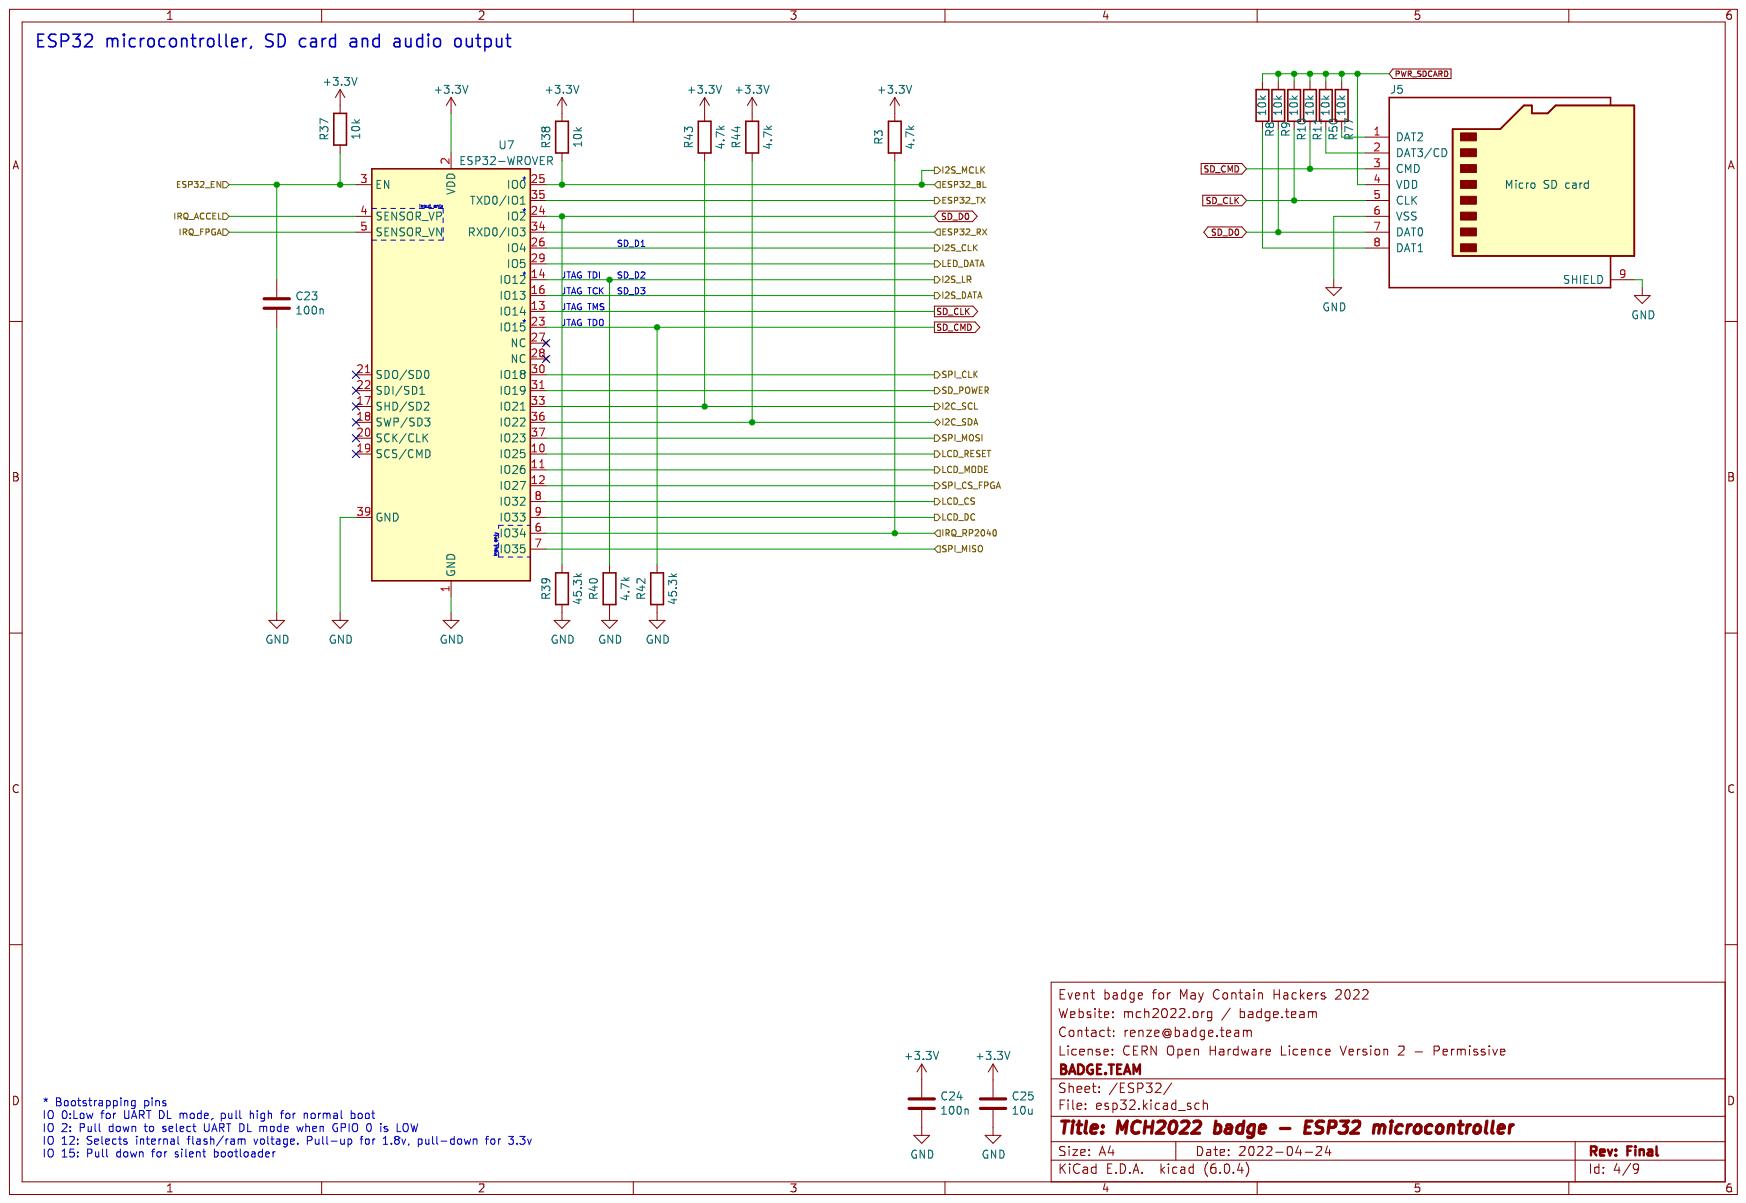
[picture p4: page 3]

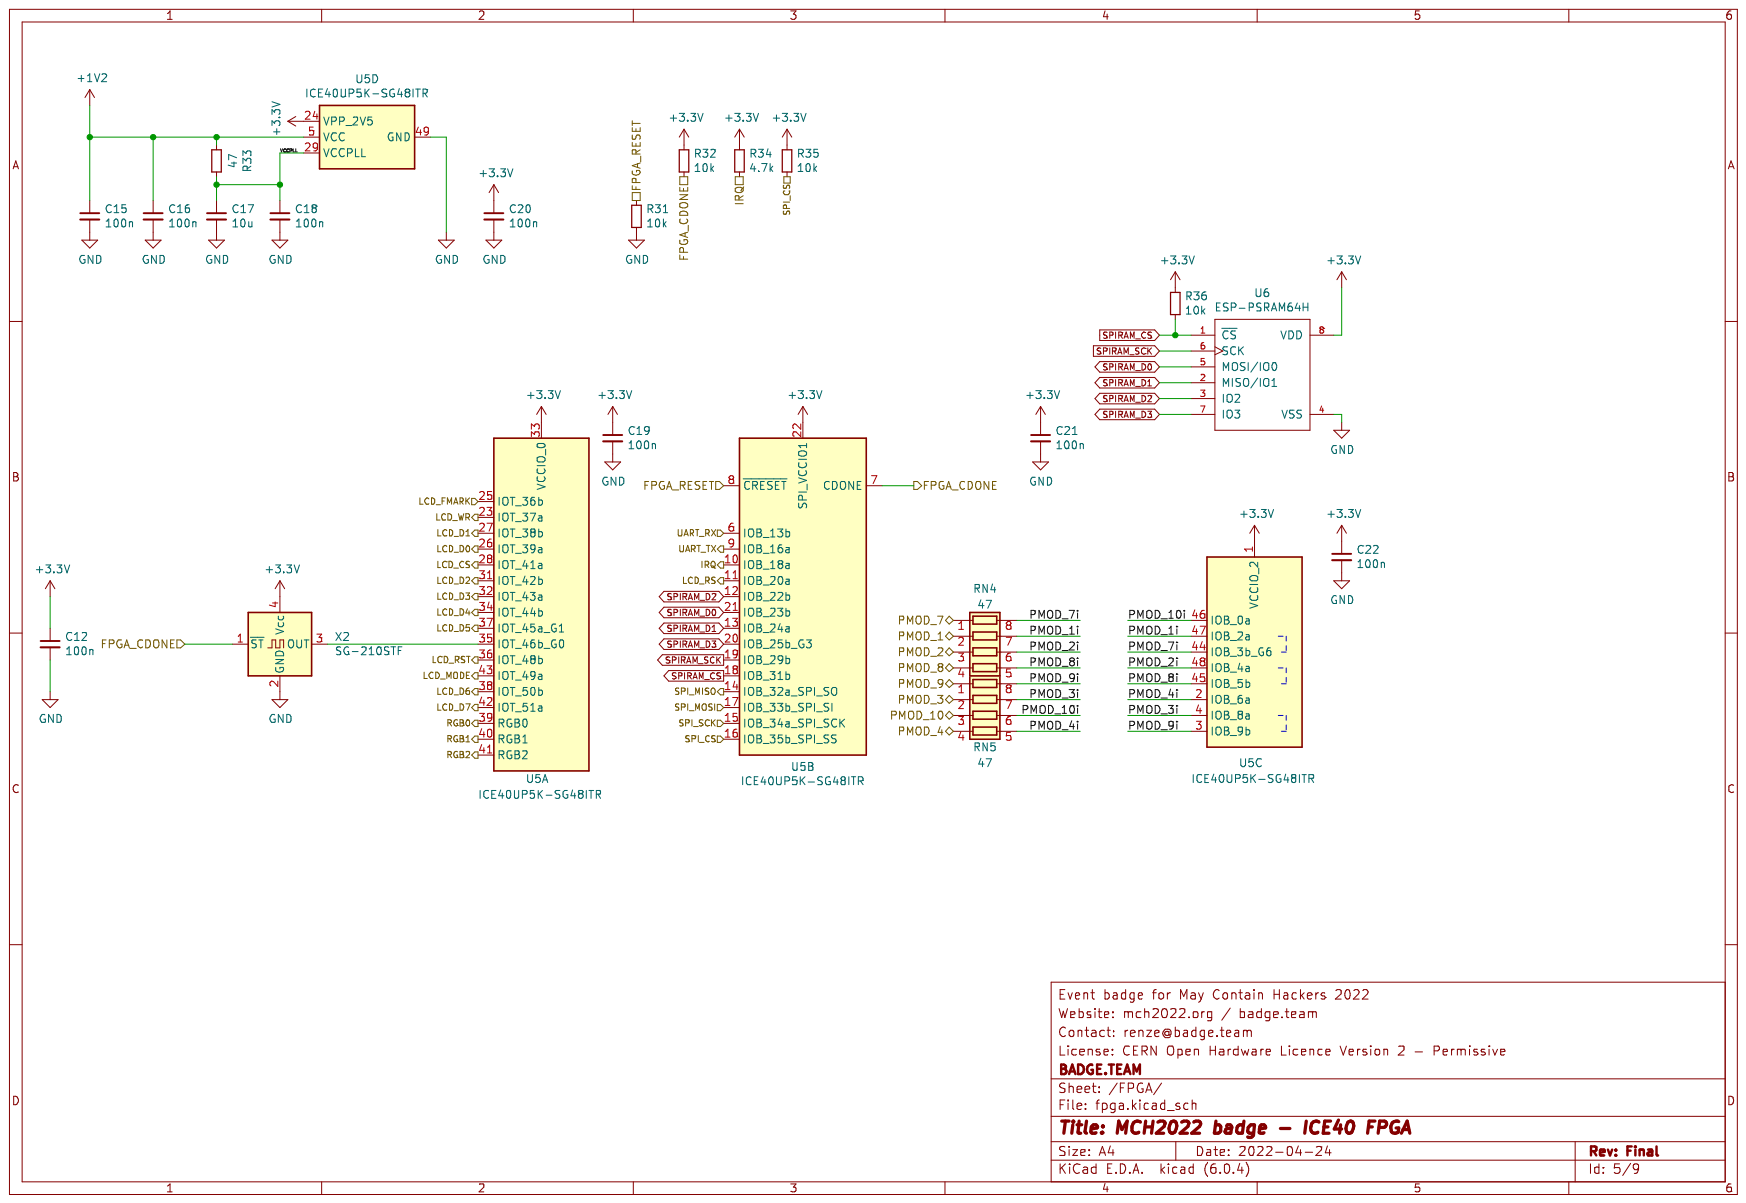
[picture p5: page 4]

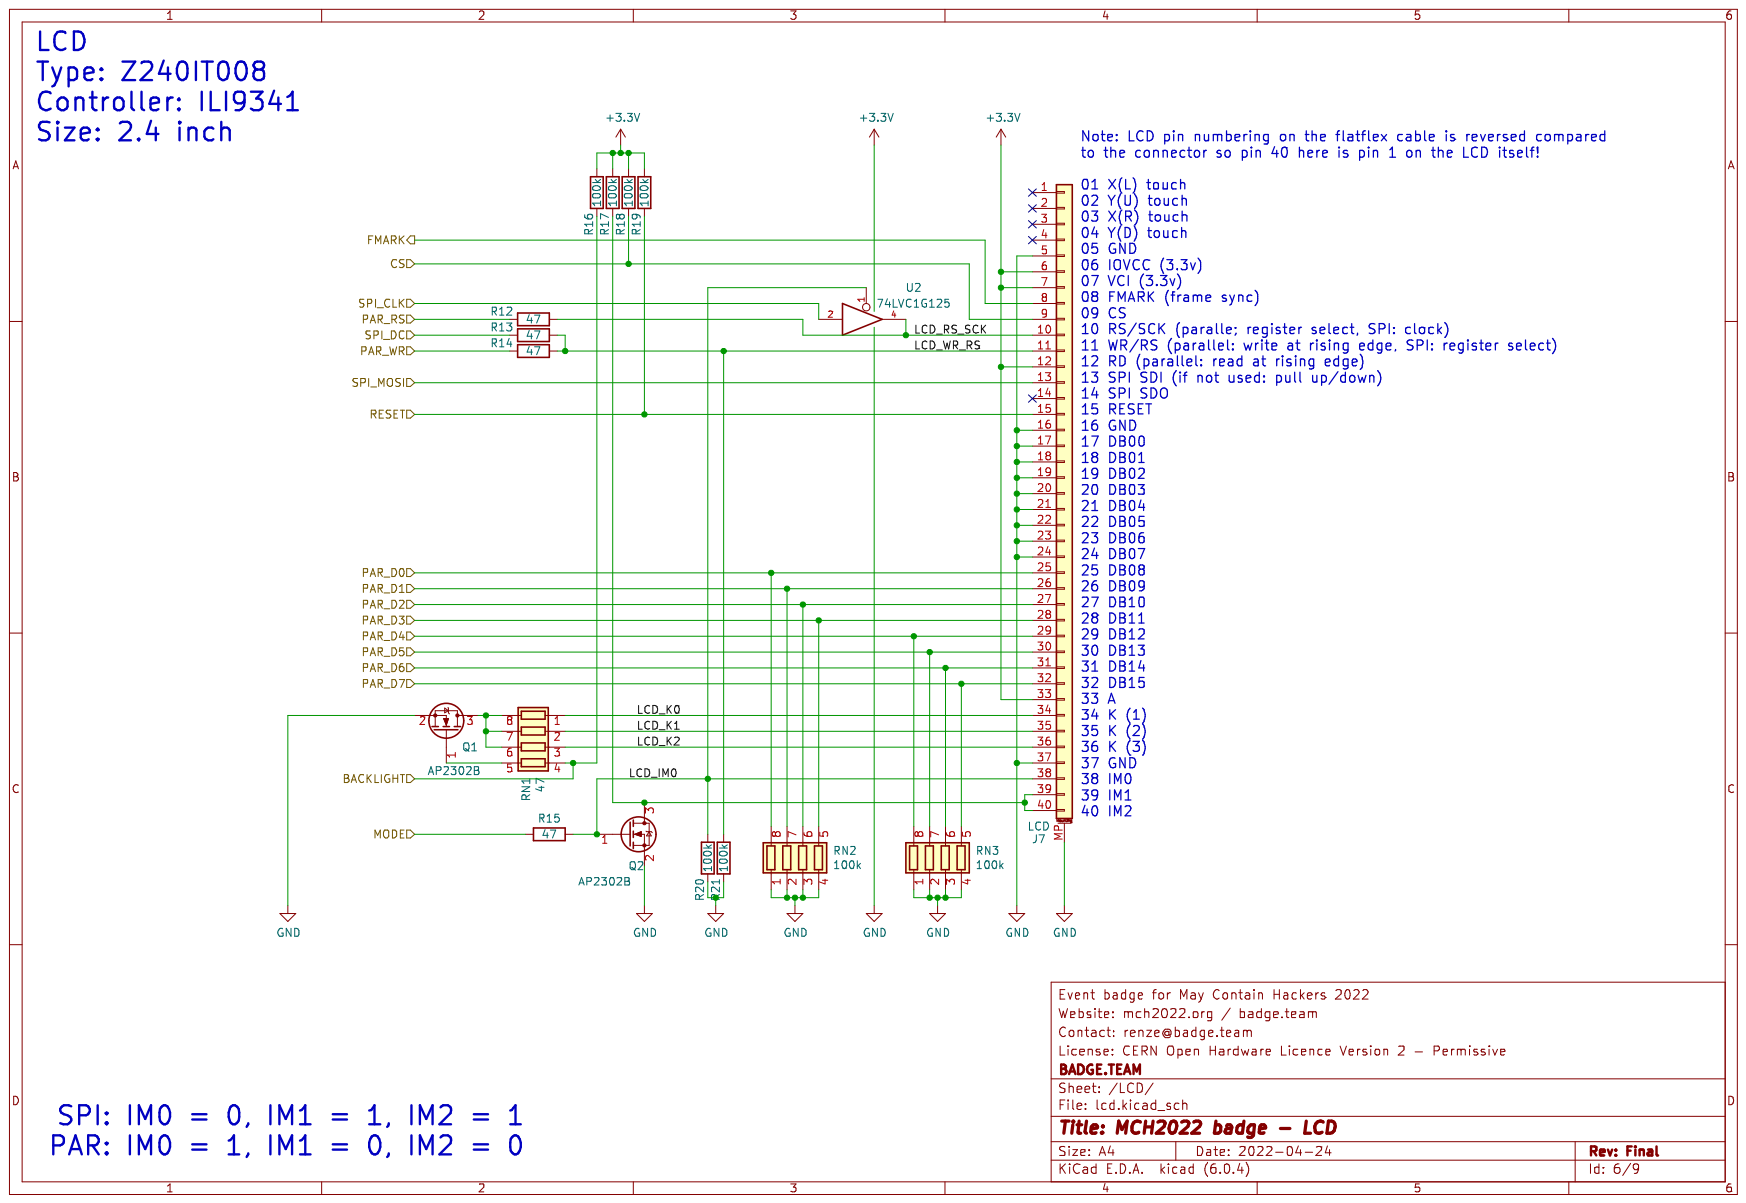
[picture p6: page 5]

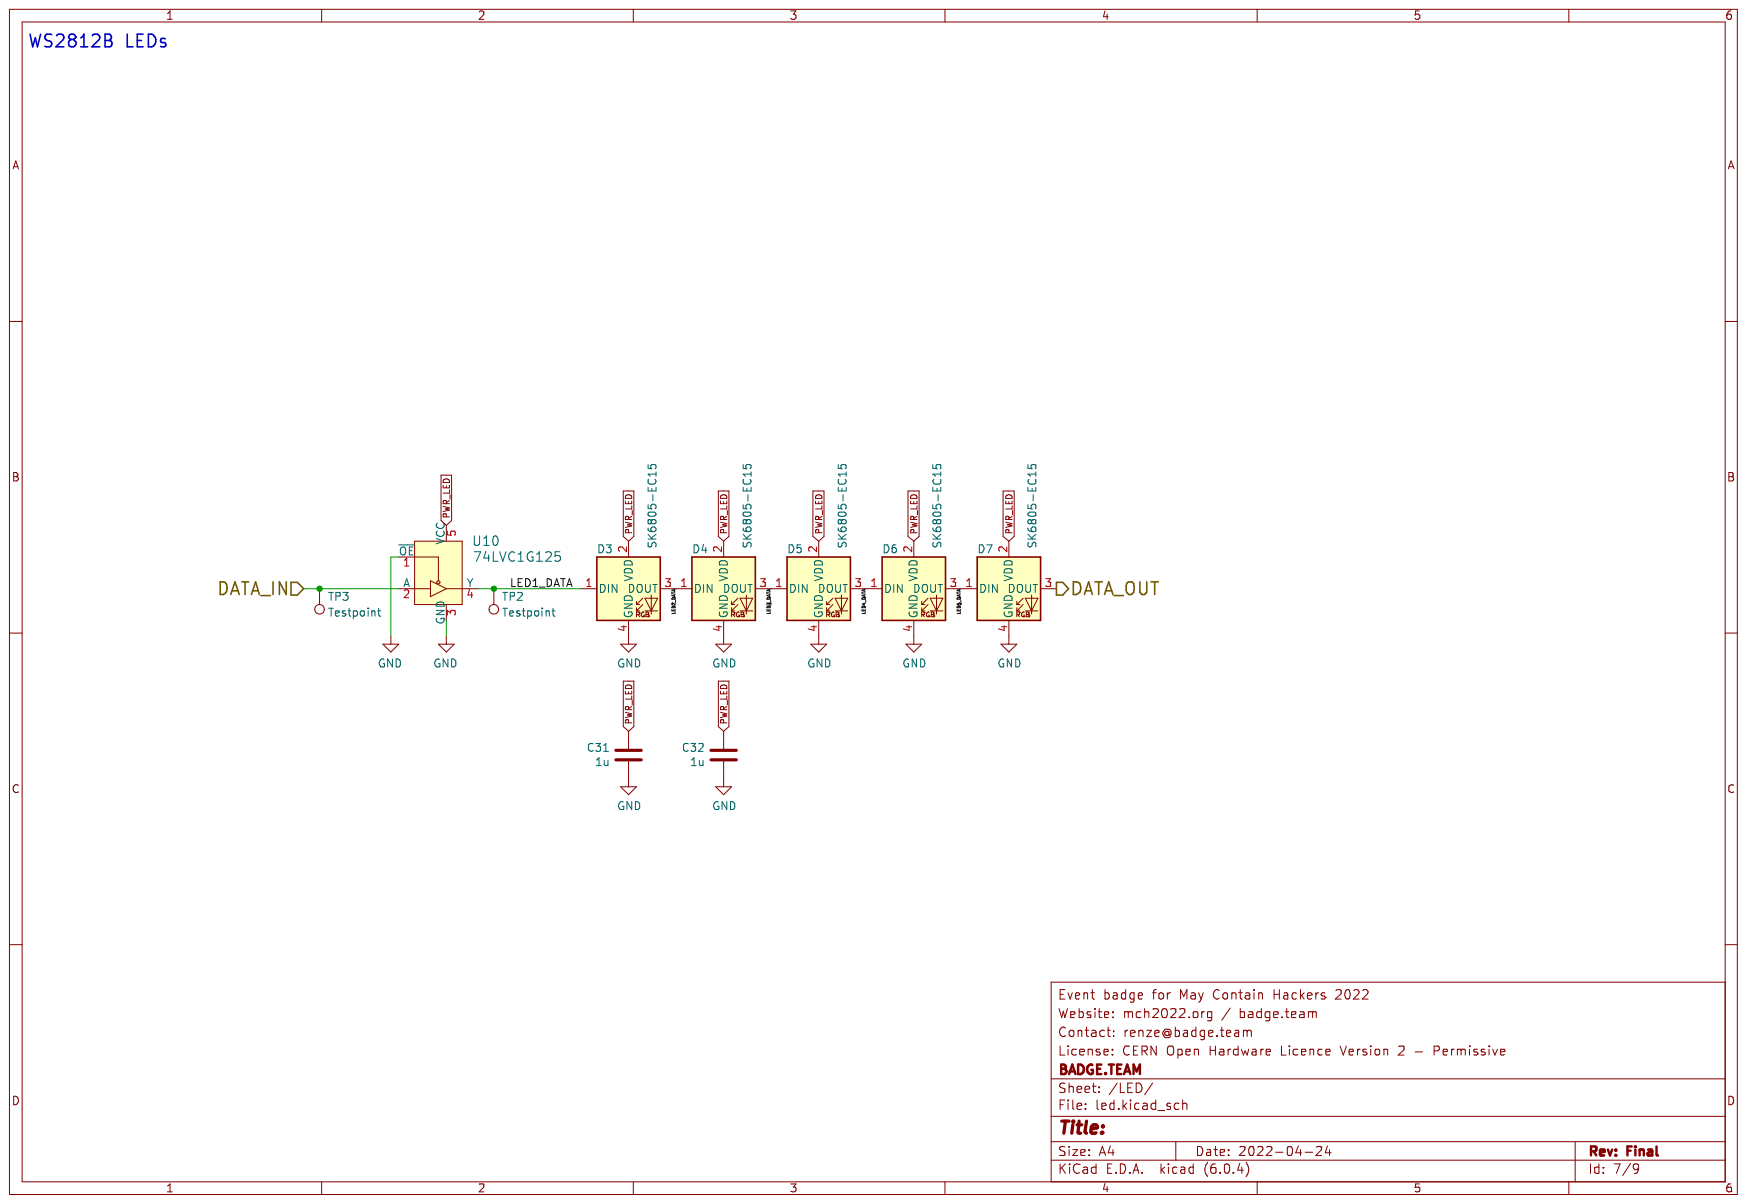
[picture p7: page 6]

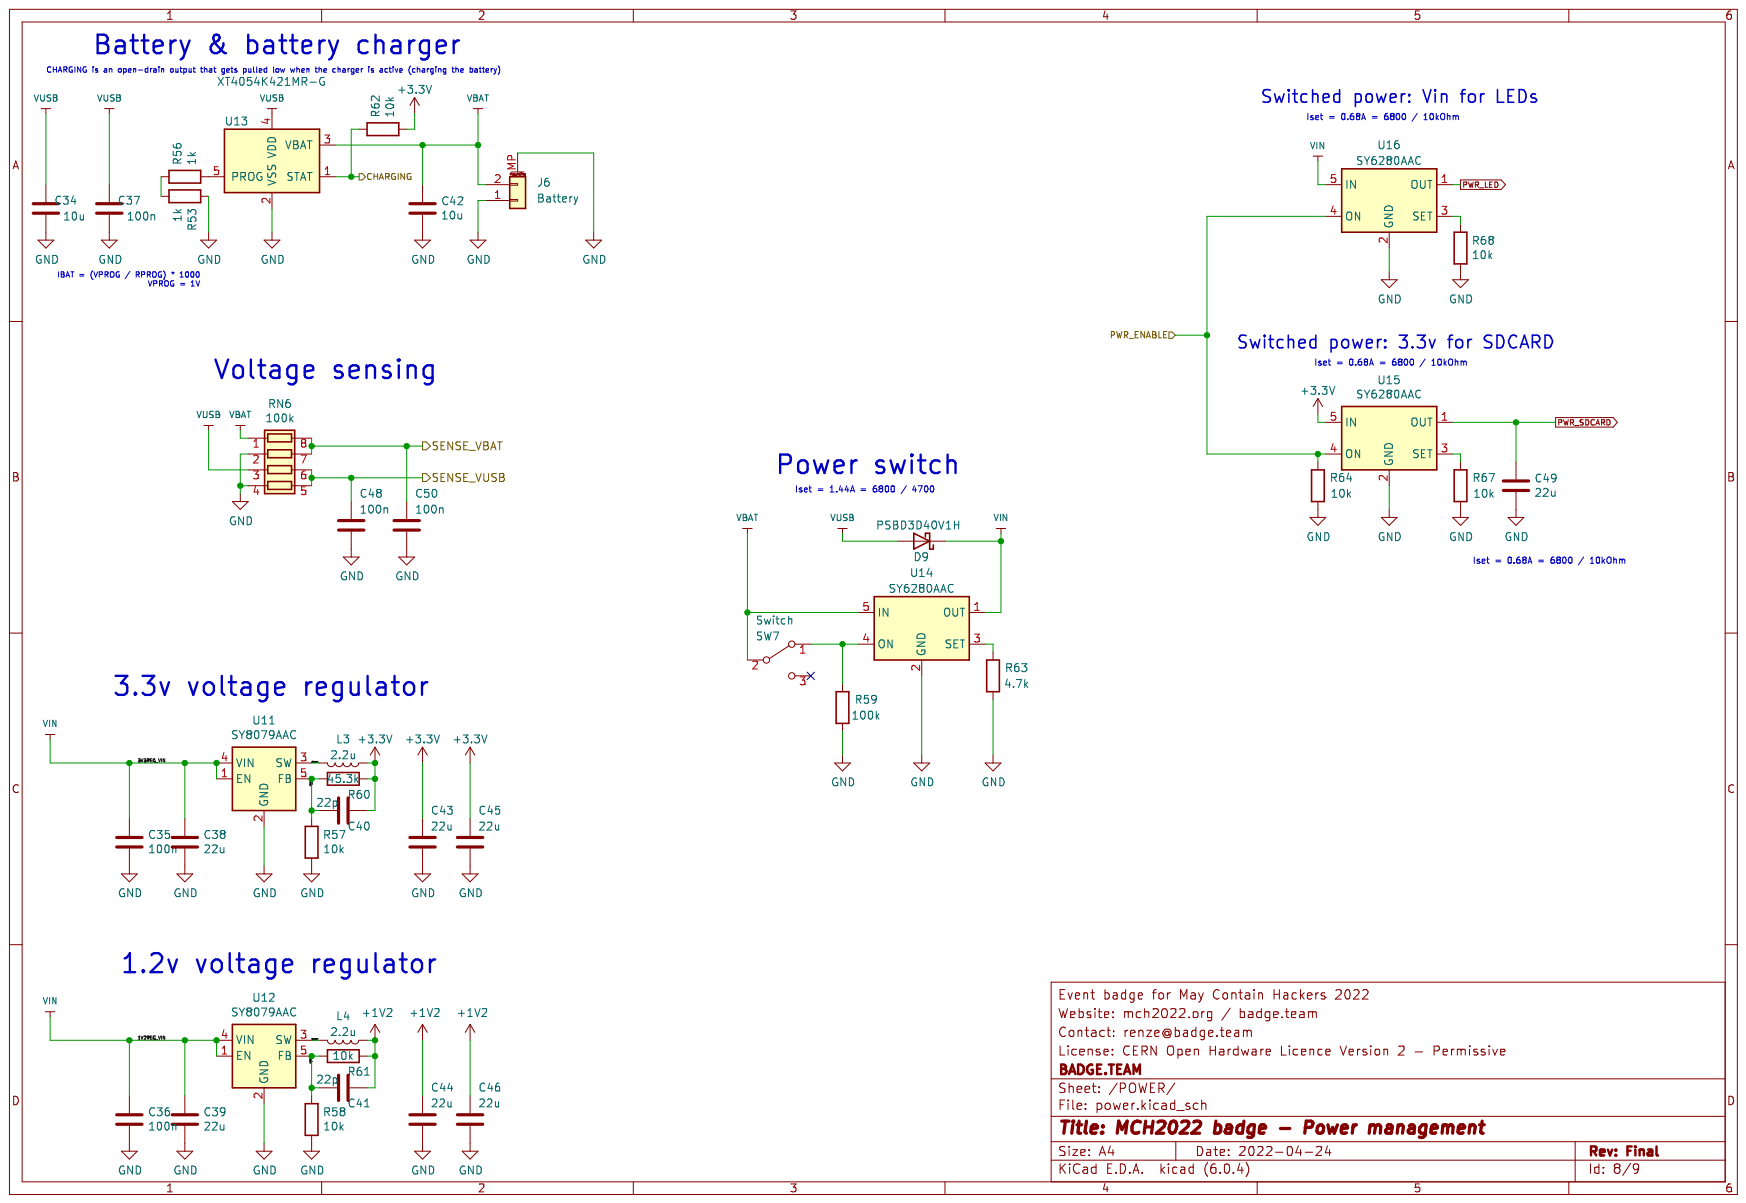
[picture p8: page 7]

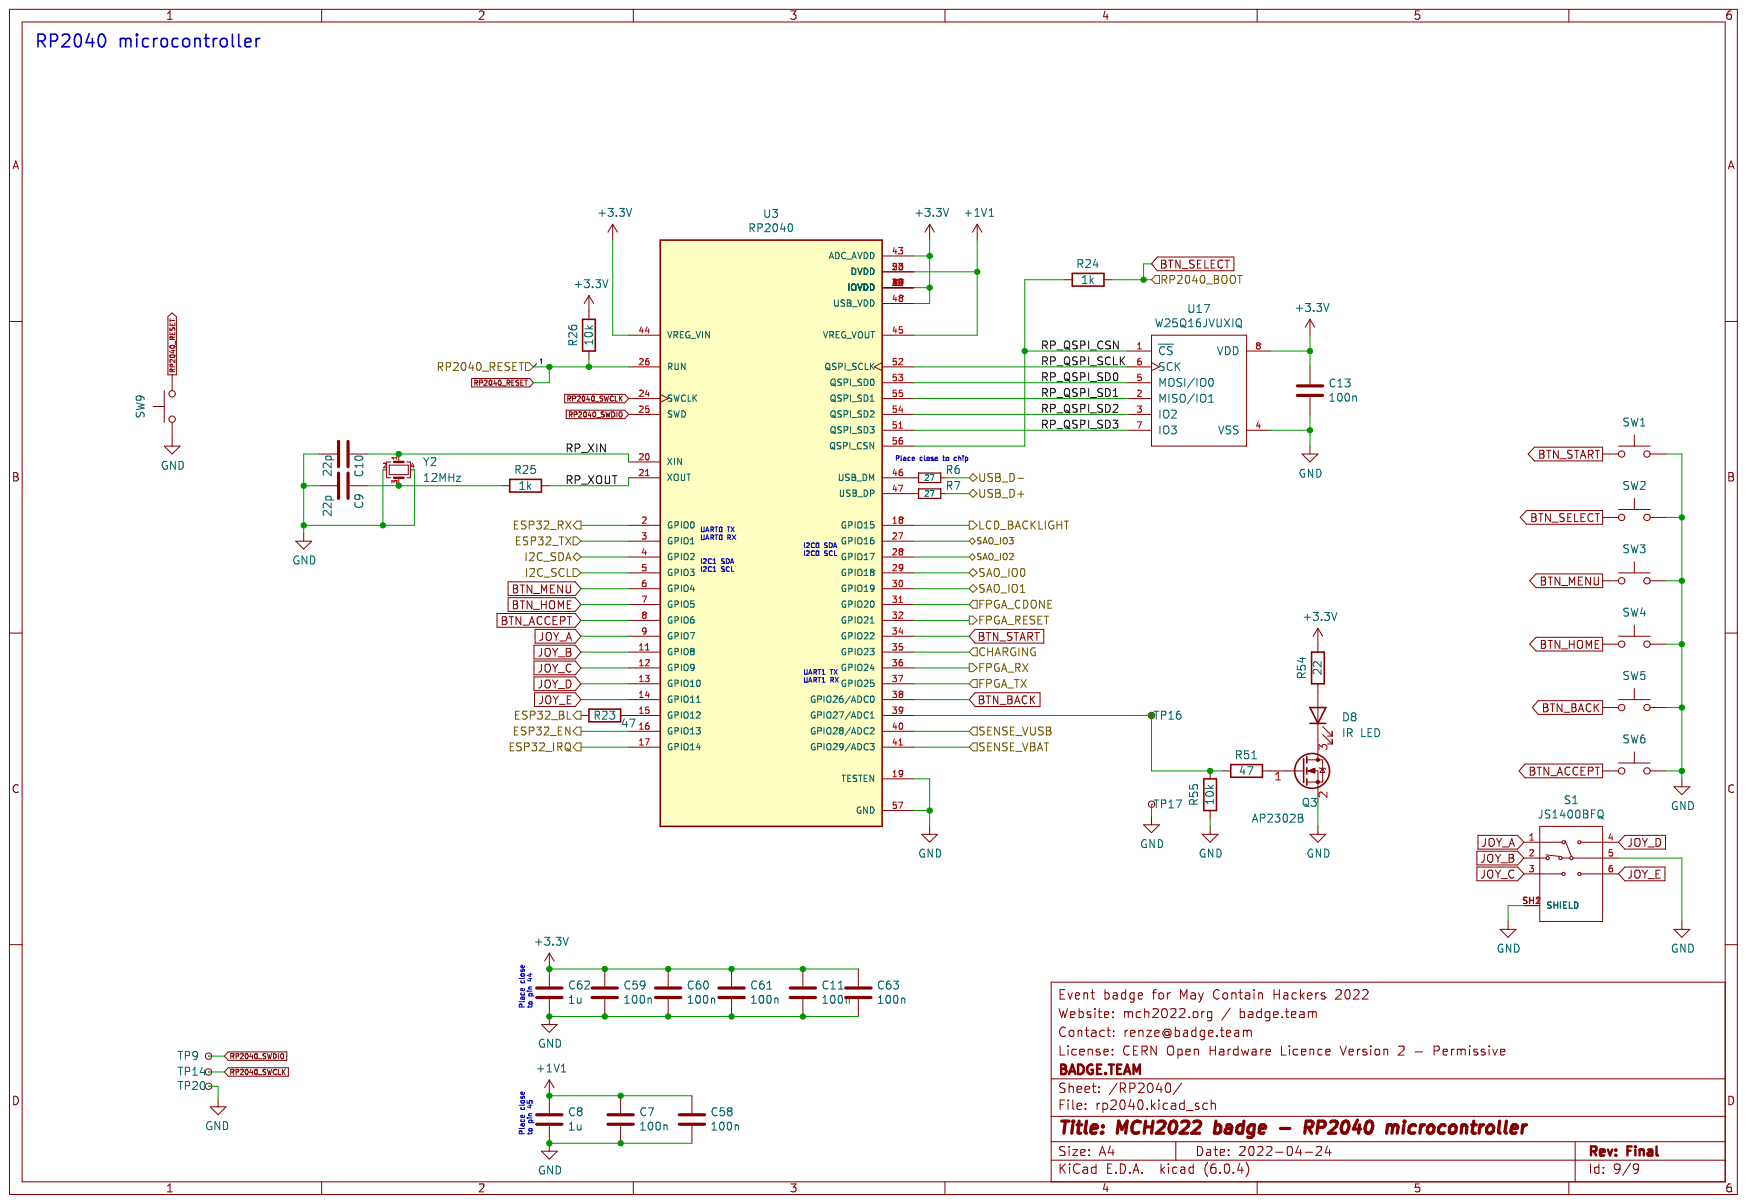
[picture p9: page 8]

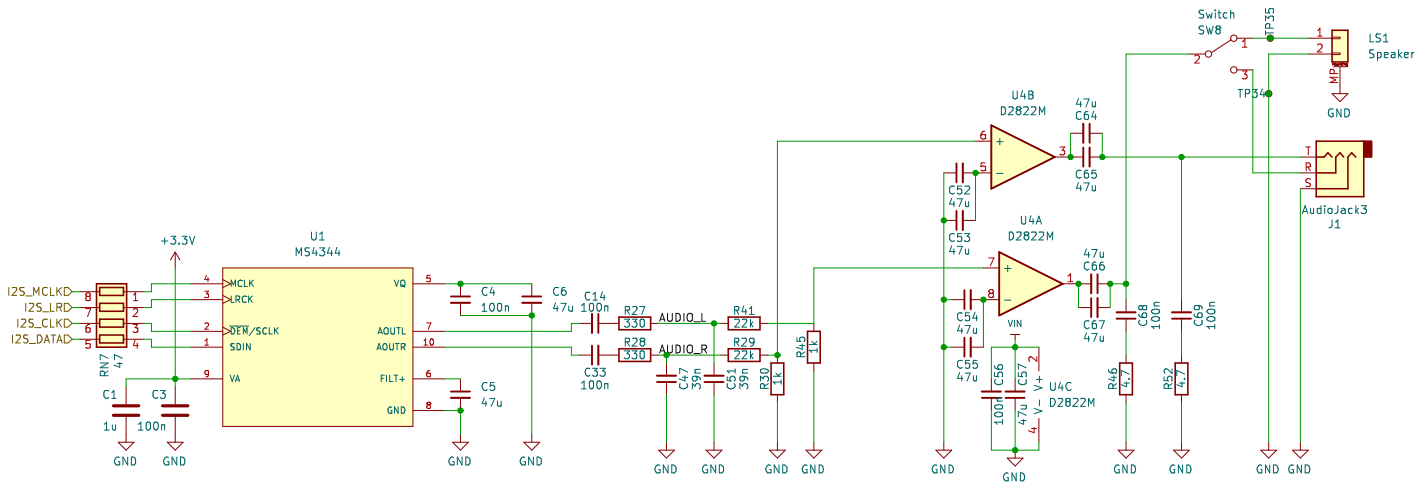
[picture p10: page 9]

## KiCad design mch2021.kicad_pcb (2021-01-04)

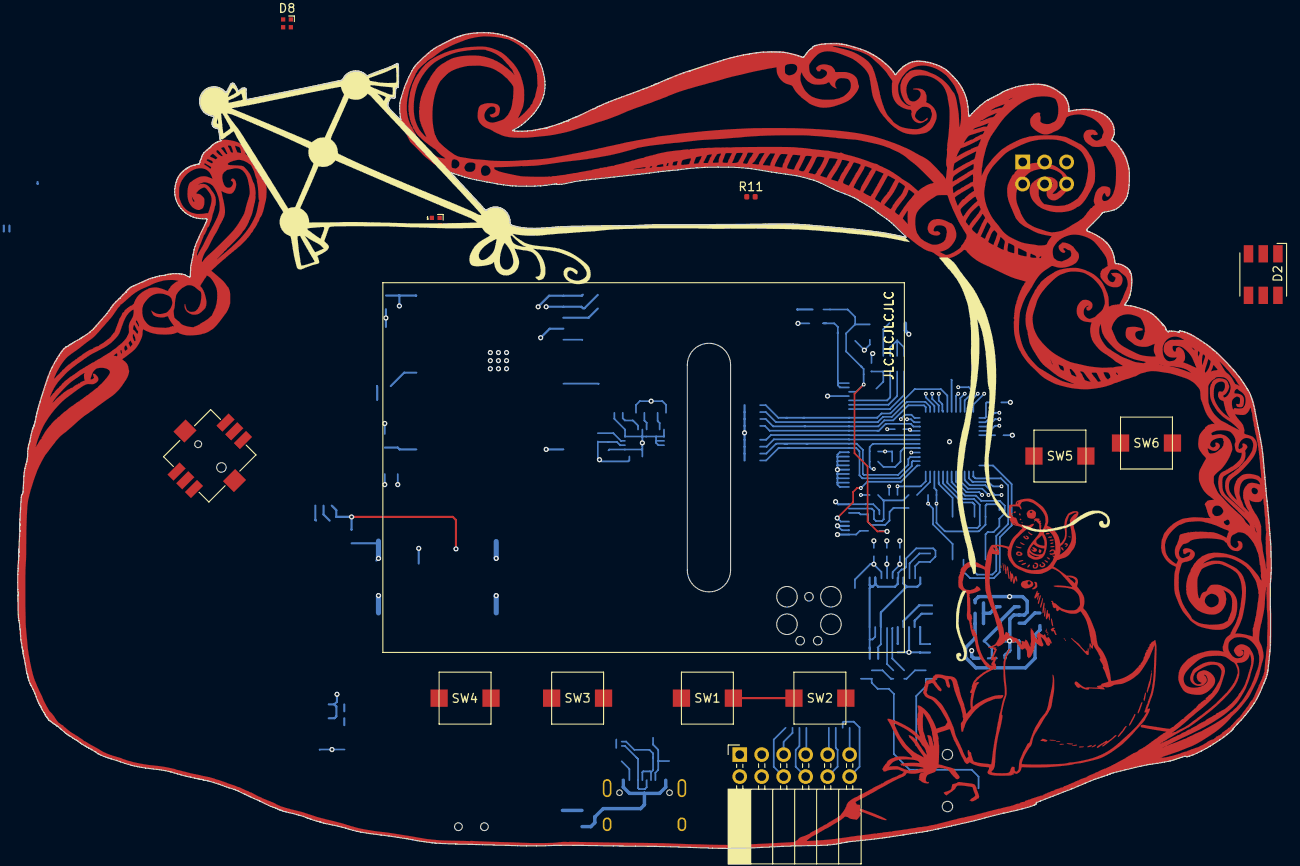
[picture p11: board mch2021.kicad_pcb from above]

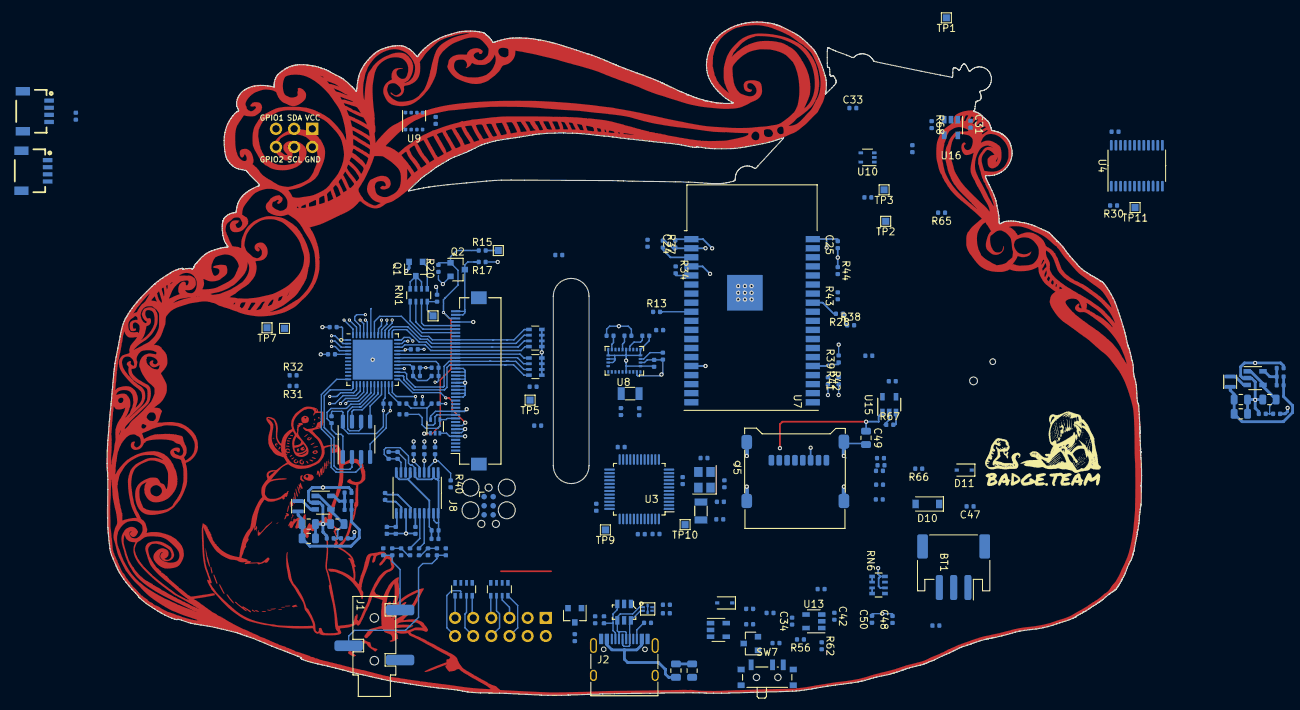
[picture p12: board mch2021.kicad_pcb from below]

Board: 4 copper layers, 144.8 x 94.3 mm, 204 parts (186 on the bottom side), 168 nets.

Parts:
BT1: LiPo; JST_PH_S3B-PH-SM4-TB_1x03-1MP_P2.00mm_Horizontal
C1, C5, C31, C32, C33, C53: 1u; C_0402_1005Metric
C2, C6, C11, C12, C14, C15, C16, C18, C19, C20, C21, C22, C23, C24, C26, C27, C30, C37, C47, C48, C50, C54: 100n; C_0402_1005Metric
C3, C4: 2.2u; C_0402_1005Metric
C7, C8, C9, C10, C28, C29, C40, C41: 22p; C_0402_1005Metric
C17, C25, C34, C42: 10u; C_0402_1005Metric
C35, C36: DNP; C_0402_1005Metric
C38, C39, C43, C44, C45, C46, C49: 22u; C_0805_2012Metric
C51, C52: 2.2n; C_0402_1005Metric
Cr: 100n; C_0402_1005Metric
D1: USBLC6-4SC6; SOT23-6L
D2: RGB-5050; LED_RGB_5050-6
D3, D4, D5, D6, D7, D8: SK6812-EC15; LED_SK6812_EC15_1.5x1.5mm
D9: NSVR0320MW2T1G; D_SOD-323
D10: 1N4148W; D_SOD-123
D11: 3V3; D_SOD-323
F1: 1A; Fuse_0805_2012Metric
J1: AudioJack3; Boom-audiojack-PJ-320B
J2: USB_C_Receptacle_USB2.0; USB_C_Receptacle_HRO_TYPE-C-31-M-12
J3, J6: QWIIC_CONNECTORJS-1MM; 1X04_1MM_RA
J4: PMOD; PinSocket_2x06_P2.54mm_Horizontal
J5: Micro SD card; MicroSD-SOFNG-TF-002-H18
J7: LCD; Hirose_FH12-40S-0.5SH_1x40-1MP_P0.50mm_Horizontal
J8: JTAG; Tag-Connect_TC2030-IDC-FP_2x03_P1.27mm_Vertical
L1: 22 Ohm; R_0805_2012Metric
L2: L_Core_Ferrite_Coupled_Small_GND; MCE1012E900FBP
L3, L4: 2.2u; Inductor_MSC20FC
N1: Badge.team; badgeteam
N2: Artwork; vector4
Q1, Q2, Q3, Q4: Q_NMOS_GSD; SOT-23
R1, R2: 5k1; R_0402_1005Metric
R3, R4, R5, R50, R73, R74: 470; R_0402_1005Metric
R6, R7, R8, R9, R10, R11, R24, R25, R26, R29, R31, R35, R36, R37, R38, R54, R55, R57, R58, R61, R63, R64, R65, R67: 10k; R_0402_1005Metric
R12, R13, R14, R15, R22, R23, R33: 47; R_0402_1005Metric
R16, R17, R18, R19, R20, R21, R28, R53, R59, R66: 100k; R_0402_1005Metric
R27, R32, R41, R69, R70: DNP; R_0402_1005Metric
R30, R34, R47, R48, R49: 4k7; R_0402_1005Metric
R39, R42, R60: 45.3k; R_0402_1005Metric
R40, R43, R44, R45, R46: 4.7k; R_0402_1005Metric
R51, R52, R71, R72: 0; R_0402_1005Metric
R56, R62: 2k; R_0402_1005Metric
R68: 3.4k; R_0402_1005Metric
RN1, RN4, RN5: 47; R_Array_Convex_4x0603
RN2, RN3, RN6: 100k; R_Array_Convex_4x0603
S1: JS1400BFQ; SW_JS1400BFQ
SW1: Start; 1TS009
SW2: Select; 1TS009
SW3: Menu; 1TS009
SW4: Home; 1TS009
SW5: Back; 1TS009
SW6: Accept; 1TS009
SW7: Power switch; SW_SPDT_PCM12
TP1: LED OUT; TestPoint_Pad_1.0x1.0mm
TP2, TP3: LED IN; TestPoint_Pad_1.0x1.0mm
TP4: LCD MODE; TestPoint_Pad_1.0x1.0mm
TP5: LCD RESET; TestPoint_Pad_1.0x1.0mm
TP6: LCD BACKLIGHT; TestPoint_Pad_1.0x1.0mm
TP7: FPGA RX; TestPoint_Pad_1.0x1.0mm
TP8: FPGA TX; TestPoint_Pad_1.0x1.0mm
TP9: MCO; TestPoint_Pad_1.0x1.0mm
TP10: STM32 RESET; TestPoint_Pad_1.0x1.0mm
TP11: STM32 BOOT0; TestPoint_Pad_1.0x1.0mm
U1: PCM5100; TSSOP-20_4.4x6.5mm_P0.65mm
U2, U10: 74LVC1G125; SOT-353_SC-70-5
U3: STM32F103C8Tx; LQFP-48_7x7mm_P0.5mm
U4: PCA9555PW; TSSOP-24_4.4x7.8mm_P0.65mm
U5: ICE40UP5K-SG48ITR; QFN-48-1EP_7x7mm_P0.5mm_EP5.6x5.6mm
U6: LY68L6400; SOIC-8-1EP_3.9x4.9mm_P1.27mm_EP2.41x3.81mm
U7: ESP32-WROVER
U8: BNO055; LGA-28_5.2x3.8mm_BNO0055
U9: BME680; Bosch_LGA-8_3x3mm_P0.8mm_ClockwisePinNumbering
U11, U12: SY8079AAC; SOT-23-5
U13: XT4054K421MR-G; SOT-23-5
U14, U15, U16: SY6280AAC; SOT-23-5
X1: Simple_Addon_v2; Simple_Addon_v2-BADGE-2x3-nosilk
Y1, Y3: 32kHz; Crystal_SMD_3215-2Pin_3.2x1.5mm
Y2: 16MHz; Crystal_SMD_3225-4Pin_3.2x2.5mm

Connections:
+1V2: C15.1, C16.1, C41.1, C44.1, C46.1, L4.1, R33.1, R61.1, U5.5, U5.30
+3V3: C5.1, C6.1, C11.1, C12.1, C14.1, C19.1, C20.1, C21.1, C22.1, C24.1, C25.1, C26.1, C30.1, C40.1, C43.1, C45.1, C53.1, C54.1, Cr.1, D2.4, D2.5, D2.6, J3.2, J4.1, J4.2, J6.2, J7.6, J7.7, J7.12, J7.33, J8.1, L3.1, R16.1, R17.1, R18.1, R19.1, R24.2, R26.1, R27.1, R28.1, R30.1, R32.1, R34.1, R35.1, R36.1, R37.1, R38.1, R41.1, R43.1, R44.1, R45.1, R46.1, R47.1, R48.1, R49.1, R60.1, R62.2, U1.1, U1.8, U1.17, U1.20, U2.5, U3.9, U3.24, U3.36, U3.48, U4.2, U4.3, U4.24, U5.1, U5.22, U5.24, U5.33, U6.8, U7.2, U8.3, U8.28, U9.2, U9.5, U9.6, U9.8, U15.5, X1.1
/BOSCH/BNO055_CAP: C27.1, U8.9
/BOSCH/BNO055_XIN32: C28.1, U8.27, Y3.2
/BOSCH/BNO055_XOUT32: C29.1, U8.26, Y3.1
/BOSCH/BOOT: R25.2, R48.2, TP11.1, U3.44, U4.5, U8.4
/BOSCH/INT: R49.2, U7.4, U8.14
/BUTTONS/BNO055_RESET: R47.2, U4.8, U8.11
/BUTTONS/BTN_HOME: SW4.1, U4.13
/BUTTONS/BTN_MENU: SW3.1, U4.11
/BUTTONS/BTN_SELECT: SW2.1, U4.10
/BUTTONS/BTN_START: SW1.1, U4.9
/BUTTONS/FPGA_CDONE: R32.2, U4.7, U5.7
/BUTTONS/FPGA_RESET: R31.1, U4.6, U5.8
/BUTTONS/I2C_SCL: J3.4, R43.2, U3.21, U4.22, U7.33, U8.19, U9.4
/BUTTONS/I2C_SDA: J3.3, R44.2, U3.22, U4.23, U7.36, U8.20, U9.3
/CC1: D1.3, J2.A5, R1.2, R22.2
/CC2: J2.B5, R2.2
/ESP32/ESP32_BL: R23.1, R38.2, U7.25
/ESP32/ESP32_EN: C23.1, R37.2, U3.18, U7.3
/ESP32/ESP32_RX: U3.30, U7.34
/ESP32/ESP32_TX: U3.31, U7.35
/ESP32/EXT_I2C_SCL: J6.4, R45.2, U7.10, X1.4
/ESP32/EXT_I2C_SDA: J6.3, R46.2, U7.11, X1.3
/ESP32/LCD_DC: R13.2, U7.9
/ESP32/SD_CLK: J5.5, R8.2, U7.13
/ESP32/SD_CMD: J5.3, R9.2, R41.2, R42.1, U7.23
/ESP32/SD_D0: J5.7, R7.2, R39.1, U7.24
/ESP32/SPI_CLK: U2.2, U3.15, U5.15, U7.30
/ESP32/SPI_MISO: U3.16, U5.14, U7.7
/ESP32/SPI_MOSI: J7.13, U3.17, U5.17, U7.37
/FPGA/CLK: TP9.1, U3.29, U5.35
/FPGA/IRQ: R34.2, U5.10, U7.5
/FPGA/LCD_D0: J7.25, RN2.8, U5.26
/FPGA/LCD_D1: J7.26, RN2.7, U5.27
/FPGA/LCD_D2: J7.27, RN2.6, U5.31
/FPGA/LCD_D3: J7.28, RN2.5, U5.32
/FPGA/LCD_D4: J7.29, RN3.8, U5.34
/FPGA/LCD_D5: J7.30, RN3.7, U5.37
/FPGA/LCD_D6: J7.31, RN3.6, U5.38
/FPGA/LCD_D7: J7.32, RN3.5, U5.42
/FPGA/LCD_RS: R12.2, U5.11
/FPGA/LCD_WR: R14.2, U5.23
/FPGA/PMOD_1: J4.12, RN4.2
/FPGA/PMOD_1i: RN4.7, U5.47
/FPGA/PMOD_2: J4.10, RN4.3
/FPGA/PMOD_2i: RN4.6, U5.48
/FPGA/PMOD_3: J4.8, RN5.2
/FPGA/PMOD_3i: RN5.7, U5.4
/FPGA/PMOD_4: J4.6, RN5.4
/FPGA/PMOD_4i: RN5.5, U5.2
/FPGA/PMOD_7: J4.11, RN4.1
/FPGA/PMOD_7i: RN4.8, U5.44
/FPGA/PMOD_8: J4.9, RN4.4
/FPGA/PMOD_8i: RN4.5, U5.45
/FPGA/PMOD_9: J4.7, RN5.1
/FPGA/PMOD_9i: RN5.8, U5.3
/FPGA/PMOD_10: J4.5, RN5.3
/FPGA/PMOD_10i: RN5.6, U5.46
/FPGA/RGB0: D2.1, U5.39
/FPGA/RGB1: D2.3, U5.40
/FPGA/RGB2: D2.2, U5.41
/FPGA/SPI_CS: R35.2, U5.16, U7.12
/FPGA/VCCPLL: C17.1, C18.1, R33.2, U5.29
/LCD/BACKLIGHT: R16.2, RN1.4, TP6.1, U3.46
/LCD/CS: J7.9, R18.2, U7.8
/LCD/FMARK: J7.8, U5.25
/LCD/LCD_IM0: J7.38, Q2.1, R15.1, R20.2, U2.1
/LCD/LCD_K0: J7.34, RN1.1
/LCD/LCD_K1: J7.35, RN1.2
/LCD/LCD_K2: J7.36, RN1.3
/LCD/LCD_RS_SCK: J7.10, R12.1, U2.4
/LCD/LCD_WR_RS: J7.11, R13.1, R14.1, R21.2
/LED/DATA_IN1: R50.2, TP2.1, U7.29
/LED/DATA_IN2: R50.1, TP3.1, U3.42, U10.2
/LED/DATA_OUT: D8.2, TP1.1
/PCM5100_CAPN: C3.2, U1.4
/PCM5100_CAPP: C3.1, U1.2
/PCM5100_LDOO: C1.1, C2.1, U1.18
/PCM5100_OUTL: R73.1, U1.6
/PCM5100_OUTR: R74.1, U1.7
/PCM5100_VNEG: C4.1, U1.5
/POWER/1V2REG_VIN: C36.1, C39.1, R52.1, U12.1, U12.4
/POWER/3V3REG_VIN: C35.1, C38.1, R51.1, U11.1, U11.4
/POWER/CHARGING: R62.1, U3.20, U13.1
/POWER/FB12: C41.2, R58.1, R61.2, U12.5
/POWER/FB33: C40.2, R57.1, R60.2, U11.5
/POWER/PWR_LED_ENABLE: R65.2, U3.27, U16.4
/POWER/PWR_SDCARD_ENABLE: R64.2, U3.28, U15.4
/POWER/SENSE_VBAT: C50.1, RN6.7, RN6.8, U3.11
/POWER/SENSE_VUSB: C48.1, RN6.5, RN6.6, U3.10
/POWER/SW12: L4.2, U12.3
/POWER/SW33: L3.2, U11.3
/STM32/ESP32_WK: R30.2, U3.39, U4.1, U7.6
/STM32/FPGA_RX: TP7.1, U3.12, U5.6
/STM32/FPGA_TX: TP8.1, U3.13, U5.9
/STM32/LCD_MODE: R15.2, TP4.1, U3.41
/STM32/LCD_RESET: J7.15, R19.2, TP5.1, U3.40
/STM32/SPI_CS: R28.2, U3.14, U7.31
/STM32/USB_D+: L2.4, R27.2, R29.1, U3.33
/STM32/USB_D-: L2.2, U3.32
/USB_D+: D1.6, J2.A6, J2.B6, L2.3
/USB_D-: D1.4, J2.A7, J2.B7, L2.1
/USB_VBUS: J2.A4, J2.A9, J2.B4, J2.B9, L1.2
BAT_3.3: C47.1, D11.1, R66.1, U3.1
ESP_I2S_CLK: R5.2, R40.1, U1.13, U7.14
ESP_I2S_DATA: R4.2, U1.14, U7.16
ESP_I2S_LR: R3.2, U1.15, U7.26
FPGA_I2S_CLK: R5.1, U5.28
FPGA_I2S_DATA: R4.1, U5.36
FPGA_I2S_LR: R3.1, U5.43
GND: BT1.2, C1.2, C2.2, C4.2, C5.2, C6.2, C7.2, C8.2, C9.2, C10.2, C11.2, C12.2, C14.2, C15.2, C16.2, C17.2, C18.2, C19.2, C20.2, C21.2, C22.2, C23.2, C24.2, C25.2, C26.2, C27.2, C28.2, C29.2, C30.2, C31.2, C32.2, C33.2, C34.1, C35.2, C36.2, C37.1, C38.2, C39.2, C42.2, C43.2, C44.2, C45.2, C46.2, C47.2, C48.2, C49.2, C50.2, C51.2, C52.2, C53.2, C54.2, Cr.2, D1.2, D3.3, D4.3, D5.3, D6.3, D7.3, D8.3, D11.2, J1.S, J2.A1, J2.A12, J2.B1, J2.B12, J2.S1, J3.1, J4.3, J4.4, J5.6, J5.9, J6.1, J7.5, J7.16, J7.17, J7.18, J7.19, J7.20, J7.21, J7.22, J7.23, J7.24, J7.37, J8.5, L2.5, L2.6, Q1.2, Q2.2, Q3.2, Q4.2, R1.1, R2.1, R20.1, R21.1, R25.1, R31.2, R39.2, R40.2, R42.2, R53.2, R56.2, R57.2, R58.2, R59.1, R63.1, R64.1, R65.1, R67.1, R68.2, R69.1, R70.1, RN2.1, RN2.2, RN2.3, RN2.4, RN3.1, RN3.2, RN3.3, RN3.4, RN6.2, RN6.4, S1.5, S1.SH1, S1.SH2, SW1.2, SW2.2, SW3.2, SW4.2, SW5.2, SW6.2, U1.3, U1.9, U1.10, U1.11, U1.12, U1.16, U1.19, U2.3, U3.8, U3.23, U3.35, U3.47, U4.12, U4.21, U5.49, U6.4, U7.1, U7.15, U7.38, U7.39, U8.2, U8.5, U8.6, U8.10, U8.15, U8.16, U8.17, U8.18, U8.25, U9.1, U9.7, U10.1, U10.3, U11.2, U12.2, U13.2, U14.2, U15.2, U16.2, X1.2, Y2.2, Y2.4
JOY_A: S1.1, U4.14
JOY_B: S1.2, U4.15
JOY_C: S1.3, U4.16
JOY_D: S1.4, U4.17
JOY_E: S1.6, U4.18
unnamed: C7.1, U3.4, Y1.2
unnamed: C8.1, U3.3, Y1.1
unnamed: C9.1, U3.6, Y2.3
unnamed: C10.1, U3.5, Y2.1
unnamed: C51.1, R72.1, R74.2
unnamed: C52.1, R71.1, R73.2
unnamed: D3.2, D4.4
unnamed: D3.4, U10.4
unnamed: D4.2, D5.4
unnamed: D5.2, D6.4
unnamed: D6.2, D7.4
unnamed: D7.2, D8.4
unnamed: D10.1, R66.2
unnamed: F1.2, L1.1
unnamed: J1.R, R70.2, R72.2
unnamed: J1.T, R69.2, R71.2
unnamed: J5.1, R11.2
unnamed: J5.2, R10.2
unnamed: J5.8, R6.2
unnamed: J7.39, J7.40, Q2.3, R17.2
unnamed: Q1.1, RN1.5
unnamed: Q1.3, RN1.6, RN1.7, RN1.8
unnamed: Q3.1, R22.1
unnamed: Q3.3, R24.1, U3.2
unnamed: Q4.1, R55.2
unnamed: Q4.3, R54.2, R59.2, U14.4
unnamed: R23.2, U3.19
unnamed: R29.2, U3.38
unnamed: R54.1, SW7.1
unnamed: R56.1, U13.5
unnamed: R63.2, U14.3
unnamed: R67.2, U15.3
unnamed: R68.1, U16.3
unnamed: SW5.1, U4.19
unnamed: SW6.1, U4.20
PWR_LED: C31.1, C32.1, C33.1, D3.1, D4.1, D5.1, D6.1, D7.1, D8.1, U10.5, U16.1
PWR_SDCARD: C49.1, J5.4, R6.1, R7.1, R8.1, R9.1, R10.1, R11.1, U15.1
SAO0: U3.25, X1.5
SAO1: U3.26, X1.6
SPIRAM_CS: R36.2, U5.18, U6.1
SPIRAM_D0: U5.21, U6.5
SPIRAM_D1: U5.13, U6.2
SPIRAM_D2: U5.12, U6.3
SPIRAM_D3: U5.20, U6.7
SPIRAM_SCK: U5.19, U6.6
STM32_RESET: J8.3, R26.2, TP10.1, U3.7, U4.4
STM32_SWCLK: J8.4, U3.37
STM32_SWDIO: J8.2, U3.34
VBAT: BT1.3, C42.1, D10.2, RN6.1, SW7.2, U13.3, U14.5
VIN: D9.1, R51.2, R52.2, U14.1, U16.5
VUSB: C34.2, C37.2, D1.5, D9.2, F1.1, R53.1, R55.1, RN6.3, U13.4

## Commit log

2020-08-09 Finished work on initial schematic
    [accelerometer.sch, audio.sch, esp32.sch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]
2020-08-09 Small fixes
    [accelerometer.sch, audio.sch, esp32.sch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]
2020-08-10 SPI RAM for the FPGA
    [fpga.sch, mch2021.sch]
2020-08-10 Fixes, removed I2S DAC
    [accelerometer.sch, esp32.sch, fpga.sch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]
2020-08-28 33 DRC errors to go...
    [buttons.sch, fpga.sch, mch2021.kicad_pcb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]
2020-08-29 Routed and 0 DRC errors
    [buttons.sch, esp32.sch, fpga.sch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]
2020-08-29 Small tweaks
    [mch2021.kicad_pcb]
2020-08-29 Final touches
    [mch2021.kicad_pcb]
2020-08-30 Moved SAO2/3, I2C_SDA/SCL away from antenna, and LCD/CS away from hole in PCB.
    [mch2021.kicad_pcb]
2020-09-19 Add interactive BOM, add pin 1 markers to stm32 and ice40
    [mch2021.kicad_pcb]
2020-11-13 Work in progress: prototype 2
    [accelerometer.sch, esp32.sch, fpga.sch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]
2020-11-22 More work on prototype 2
    [accelerometer.sch, bosch.sch, buttons.sch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]
2020-11-29 Add testpoints, add way for STM32 to wake-up ESP32 from deep sleep
    [bosch.sch, buttons.sch, esp32.sch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]
2020-12-06 Schematic for prototype 2 is now complete, time for review! :D
    [bosch.sch, esp32.sch, fpga.sch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]
2020-12-12 Solve multiple reported issues in schematic
    [esp32.sch, fpga.sch, led.sch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]
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2020-12-13 schematic: Improve pin assignement for FPGA
    Related to issues #22, #24, #25 and #30
    [fpga.sch, mch2021.sch]
2020-12-13 Update date & pdf schematic
    [bosch.sch, buttons.sch, esp32.sch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]
2020-12-18 Add chokes to usb lines
    [bosch.sch, buttons.sch, esp32.sch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]
2020-12-18 Add jumpers
    [mch2021.sch]
2020-12-22 Updated schematic, add design file
    [bosch.sch, esp32.sch, led.sch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]
2020-12-27 Update artwork
    [draft2_test2.dxf, led.sch, mch2021.kicad_pcb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]
2020-12-27 Remove trash files
    [draft2_test2.dxf]
2020-12-29 First steps of routing prototype 2, switch to 0402 for most passives
    [bosch.sch, buttons.sch, esp32.sch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]
2020-12-30 More routing...
    [bosch.sch, fpga.sch, mch2021.kicad_pcb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]
2021-01-04 Some more work
    [bosch.sch, buttons.sch, esp32.sch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]
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2021-01-06 Layout+initial full routing
    [fpga.sch, mch2021.sch, power.sch]
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2021-01-08 Moar fixes
    [buttons.sch, led.sch, mch2021.sch]
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2021-01-08 Add via-reinforced SMD holddown pads to USB connector, headphone connector and battery connector
2021-01-10 Added expansion header, moved sdcard
    [mch2021.sch]
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2021-01-10 Clean up reference designator silkscreen
    move badgeteam logo, fix FM module trace width
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2021-01-11 Add extra IO header, add battery NTC connection
    [mch2021.sch, power.sch, stm32.sch]
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2021-01-12 Change PMOD, add silkscreen labels
    [fpga.sch, mch2021.sch]
2021-01-12 Change button LCSC id (and 3d stuff)
    [bosch.sch, buttons.sch, esp32.sch]
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2021-01-14 Reroute VIN and add a reference plane immediately below VIN trace everywhere. Fixes #50
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2021-01-14 Cosmetic fix for shielding trace
2021-01-14 Small last minute fixes
    [bosch.sch, buttons.sch, esp32.sch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]
2021-01-14 Update LCSC code for the 32kHz crystals
    [bosch.sch, mch2021.sch, stm32.sch]
2021-01-15 Add gerbers
    [mch2021-B_CrtYd.gbr, mch2021-B_Cu.gbl, mch2021-B_Mask.gbs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]
2021-01-16 Silkscreen fixes
    [mch2021-B_CrtYd.gbr, mch2021-B_Cu.gbl, mch2021-B_Mask.gbs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]
2021-01-21 Update BOM
    [bom.ods, mch2021.ods]
2021-01-24 Update bom: indicate more clearly which components are DNP and which items aren't components at all
    [bom.ods]
2021-04-05 Fix ground connections on J7 and U8
    [mch2021-B_CrtYd.gbr, mch2021-B_Cu.gbl, mch2021-B_Mask.gbs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]
2021-04-05 Change revision number in silkscreen to 2.1
    [mch2021-B_CrtYd.gbr, mch2021-B_Cu.gbl, mch2021-B_Mask.gbs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]
2021-10-09 Fix most of the bugs found on prototype 2 board
    [bosch.sch, buttons.sch, esp32.sch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]
2021-10-31 Change pinout of expansion header close to board edge to be fully ground instead of gnd + 3.3v (& update component references)
    [bosch.sch, buttons.sch, esp32.sch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]
2021-11-13 Fix symbol of 5050 led and rotate footprint to match actual LED pinout
    [bosch.sch, buttons.sch, esp32.sch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]
2021-11-13 Remove old gerbers and schematic pdf
    [mch2021-B_CrtYd.gbr, mch2021-B_Cu.gbl, mch2021-B_Mask.gbs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]
2021-11-13 Fix SK6805-EC15 footprint and symbol
    [bom.ods, led.sch]
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2021-11-14 Add gerbers, add schematic pdf, update bom
    [bom.ods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]
2021-11-28 Initial steps for RP2040
    [RP2040.step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]
2021-11-28 Connect GPIOs of the RP2040
    [mch2021.sch, rp2040.sch]
2021-11-28 Remove stm32 schematic file
    [stm32.sch]
2021-11-30 More work on RP2040 integration
    [buttons.sch, mch2021.sch, power.sch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]
2021-12-04 More wiring for the RP2040
    [mch2021.kicad_pcb, rp2040.sch]
2021-12-10 First routing pass done, no unrouted tracks except flash chip missing and DRC doesn't yet pass
    [mch2021.kicad_pcb]
2021-12-12 Add flash chip footprint, fix routing of flash chip, fix DRC errors
    [fpga.sch, mch2021.sch, rp2040.sch]
2021-12-19 Add oscillator for ICE40, add testpoints for unused RP2040 pins
    [fpga.sch, mch2021.sch, rp2040.sch]
2021-12-19 Move a wire and silkscreen fixes
2021-12-19 Add 1k resistor for RP2040 crystal, add schematic PDF
    [bosch.sch, buttons.sch, esp32.sch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]
2021-12-23 Last fixes before ordering
    [bosch.sch, buttons.sch, esp32.sch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]
2021-12-24 And of course fix the mistakes I find after ordering :(
    [mch2021-B_CrtYd.gbr, mch2021-B_Cu.gbl, mch2021-B_Mask.gbs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]
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2022-01-14 Fix badge on battery power issue, change bootsel resistor value
    [mch2021.kicad_sch, rp2040.kicad_sch]
2022-01-15 Small DRC fixes
    [mch2021.kicad_sch, power.kicad_sch]
2022-03-11 Remove IO expander, move around signals
    [bosch.kicad_sch, buttons.kicad_sch, esp32.kicad_sch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]
2022-03-11 Remove buttons schematic sheet
    [buttons.kicad_sch]
2022-03-14 Remove user I2C bus, connect LCD control signals to ESP32 directly, replace I2S dac
    [bosch.kicad_sch, esp32.kicad_sch, mch2021.kicad_sch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]
2022-03-16 Use correct flash chip for RP2040
    [esp32.kicad_sch, mch2021.kicad_sch, rp2040.kicad_sch]
2022-03-20 Add amplifier and spekaer, fixes
    [audio.kicad_sch, esp32.kicad_sch, mch2021.kicad_sch]
2022-03-20 Finishing touches for audio circuit
    [audio.kicad_sch, mch2021.kicad_sch, rp2040.kicad_sch]
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2022-03-22 Bill of materials 1/2
    [audio.kicad_sch, bosch.kicad_sch, esp32.kicad_sch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]
2022-03-22 Add new design files
    [outline.dxf]
2022-03-24 Add more info to BOM
    [audio.kicad_sch, bosch.kicad_sch, esp32.kicad_sch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]
2022-03-25 Add IR transmitter, modify bill of materials
    [audio.kicad_sch, bosch.kicad_sch, esp32.kicad_sch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]
2022-03-25 Add passives to BOM
    [audio.kicad_sch, bosch.kicad_sch, esp32.kicad_sch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]
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2022-03-27 Swap led data and sd power on ESP32, add speaker grill
    [esp32.kicad_sch, mch2021.kicad_sch]
2022-03-28 Add lanyard holes, component placement
    [audio.kicad_sch, bosch.kicad_sch, mch2021.kicad_sch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]
2022-03-29 Got some of the routing done
    [rp2040.kicad_sch]
2022-04-01 0 DRC errors, lots of warnings left to fix
    [mch2021.kicad_sch]
2022-04-02 Last minute fixes
    [audio.kicad_sch, bosch.kicad_sch, esp32.kicad_sch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]
2022-04-02 Last minute changes part 2
    [bosch.kicad_sch, esp32.kicad_sch, fpga.kicad_sch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]
2022-04-03 Last minute changes: add some more ground stitching
    [mch2021-B_Courtyard.gbr, mch2021-B_Cu.gbl, mch2021-B_Mask.gbs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]
2022-04-03 Final version of prototype 4
    [audio.kicad_sch, lcd.kicad_sch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]
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2022-04-23 Small last minute tweaks
    [audio.kicad_sch, esp32.kicad_sch, lcd.kicad_sch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]
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2022-04-24 Add gerbers, add schematic, finalize design
    [audio.kicad_sch, bosch.kicad_sch, esp32.kicad_sch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]
2022-04-24 Add component placement files
    [mch2022-bottom-pos.csv, mch2022-top-pos.csv]
2022-04-24 have you tried switching the polarity?
    [mch2022-B_Courtyard.gbr, mch2022-B_Cu.gbl, mch2022-B_Mask.gbs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]
2022-05-09 Change value of R54 to 27 ohm
    [mch2022.csv, mch2022.kicad_sch, rp2040.kicad_sch]
2022-05-09 Updated R54 in PnP file
    [mch2022-bottom-pos.csv]
2022-06-30 Mark diode as DNP, replace fuse with SMD0805B110TF
    [mch2022.kicad_sch, power.kicad_sch]
